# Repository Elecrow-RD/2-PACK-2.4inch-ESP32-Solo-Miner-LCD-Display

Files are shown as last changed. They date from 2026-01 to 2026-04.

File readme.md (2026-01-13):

### 1, Product picture

### 2, Product version number

| | Hardware | Software | Remark |
| ---- | --- | --- | --- |
| 1 | V1.0 | V1.0 | latest |

### 3, product information

| **Main Chip-ESP32-P4NRW32** | |
| --- | --- |
| CPU/SoC | **ESP32-P4**RISC-V 32-bit dual-core processor for HP systems, running at up to 400 MHz;RISC-V 32-bit single-core processor for LP systems, running at up to 40 MHz |
| System Memory | 768 KB L2MEM (HP) 32 KB SRAM (LP) 8 KB TCM 32 MB PSRAM |
| Memory | 128 KB ROM (HP) 16 KB ROM (LP) 16 MB Flash |
| Development Language | MicroPython, Rust, Lua |
| Development Environment | ESP-IDF、Arduino IDE、LVGL |
| **Screen** | |
| Size | 7.0 inch |
| Resolution | 1024*600 |
| Display Panel | IPS Panel |
| Touch Panel | Capacitive Touch, Single/5-point Touch |
| Viewing Angle | 178° |
| Brightness | 400 cd/m²(Typ.) |
| Color Depth | 16.7M (8-bit) |
| **Wireless Communication - Onboard Antenna** | |
| WiFi | Support 2.4GHz(Wi-Fi6), 802.11a/b/g/n |
| Bluetooth | Support Bluetooth 5.3 and BLE |
| Other | Zigbee, LoRa, nRF2401, Matter, Thread (**Optional**) |
| **Interface/Function** | |
| Interface | USB2.0, UART, I2C, GPIO female headers, SD card holder, battery socket, speaker jack, camera header, module female headers, etc. |
| Function | Audio amplifier, battery charge management, USB to UART, dual microphones, dual speakers etc. |
| **Button/LED Indicator** | |
| Reset Button | Yes, press to reset the device |
| Boot Button | Yes, press and hold the power button to burn the program |
| Power Button | Switch On/Off |
| PWR | Device power on/off indication |
| CHG | Lithium battery charging status, Low battery state |
| **Other** | |
| Installation method | All around mounting holes(M3 3.2mm), embedded, shell assembly |
| Operating temperature | -20~70 °C |
| Storage temperature | -30~80 °C |
| Power Input | 5V/2A, USB or UART terminal |
| Active Area | 155mm*87mm |
| Dimensions | 180*105mm |

### 4, Use the driver module

| Name | dependency library |
| ---- | --- |
| LVGL | lvgl/lvgl@8.3.11 |

### 5,Quick Start
##### Arduino IDE starts

1.Download the library files used by this product to the 'libraries' folder.

C:\Users\Documents\Arduino\libraries\



2.Open the Arduino IDE



3.Open the code configuration environment and burn it



##### ESP-IDF starts

1.Right-click on an empty space in the project folder and select "Open with VS Code" to open the project.


2.In the IDF plug-in, select the port, then compile and flash


### 6,Folder structure.
|--3D file： Contains 3D model files (.stp) for the hardware. These files can be used for visualization, enclosure design, or integration into CAD software.

|--Datasheet: Includes datasheets for components used in the project, providing detailed specifications, electrical characteristics, and pin configurations.

|--Eagle_SCH&PCB: Contains **Eagle CAD** schematic (`.sch`) and PCB layout (`.brd`) files. These are used for circuit design and PCB manufacturing.

|--example: Provides example code and projects to demonstrate how to use the hardware and libraries. These examples help users get started quickly.

|--factory_firmware: Stores pre-compiled factory firmware that can be directly flashed onto the device. This ensures the device runs the default functionality.

|--factory_sourcecode:  Contains the source code for the factory firmware, allowing users to modify and rebuild the firmware as needed.

|--libraries: Includes necessary libraries required for compiling and running the project. These libraries provide drivers and additional functionalities for the hardware.

### 7,Pin definition

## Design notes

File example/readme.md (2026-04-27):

Version **V1.0_A_green_circular_sticker_on_the_back** is a new release. In this version, the X-axis touch sensitivity is reversed compared to the previous version (1.0). All other features remain unchanged.

Version **V1.0_A_green_circular_sticker_on_the_back** has a green circular sticker on the back.


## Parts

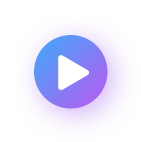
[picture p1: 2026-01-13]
example/V1.0_A_green_circular_sticker_on_the_back/IDF_Code/DHT_screen_2.4_base/components/lvgl-3/demos/music/assets/png/480_png/btn_play.png

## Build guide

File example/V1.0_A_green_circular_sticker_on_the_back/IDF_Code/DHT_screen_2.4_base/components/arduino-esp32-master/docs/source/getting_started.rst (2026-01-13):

###############
Getting Started
###############

About Arduino ESP32
-------------------

Welcome to the Arduino ESP32 support documentation! Here you will find important information on how to use the project.

First Things First
------------------

.. note::
    Before continuing, we must be clear that this project is supported by `Espressif Systems`_ and the community.
    Everyone is more than welcome to contribute back to this project.

ESP32 is a single 2.4 GHz Wi-Fi-and-Bluetooth SoC (System On a Chip) designed by `Espressif Systems`_.

ESP32 is designed for mobile, wearable electronics, and Internet-of-Things (IoT) applications. It features all the state-of-the-art characteristics 
of low-power chips, including fine-grained clock gating, multiple power modes,and dynamic power scaling. For instance, in a low-power IoT sensor 
hub application scenario, ESP32 is woken-up periodically and only when a specified condition is detected. Low-duty cycle is used to minimize the 
amount of energy that the chip expends. 

The output of the power amplifier is also adjustable, thus contributing to an optimal trade-off between communication range, data rate and 
power consumption.

The ESP32 series is available as a chip or module.

.. _supported_socs:

Supported SoC's
---------------

Here are the ESP32 series supported by the Arduino-ESP32 project:

======== ====== =========== ===================================
SoC      Stable Development Datasheet
======== ====== =========== ===================================
ESP32    Yes    Yes         `ESP32`_
ESP32-S2 Yes    Yes         `ESP32-S2`_
ESP32-C3 Yes    Yes         `ESP32-C3`_
ESP32-S3 No     Yes         `ESP32-S3`_
======== ====== =========== ===================================

See `Boards <boards/boards.html>`_ for more details about ESP32 development boards.

Arduino Core Reference
----------------------

This documentation is built on the ESP32 and we are not going to cover the common Arduino API. To see the Arduino reference documentation, 
please consider reading the official documentation.

Arduino Official Documentation: `Arduino Reference`_.

Supported Operating Systems
---------------------------

+-------------------+-------------------+-------------------+
|     |       |       |
+-------------------+-------------------+-------------------+
| Windows           | Linux             | macOS             |
+-------------------+-------------------+-------------------+





Supported IDEs
---------------------------

Here is the list of supported IDE for Arduino ESP32 support integration.

+-------------------+-------------------+
|     |         |
+-------------------+-------------------+
| Arduino IDE       | PlatformIO        |
+-------------------+-------------------+




See `Installing Guides <installing.html>`_ for more details on how to install the Arduino ESP32 support.

Support
-------

This is an open project and it's supported by the community. Fell free to ask for help in one of the community channels.

Community
---------

The Arduino community is huge! You can find a lot of useful content on the Internet.
Here are some community channels where you may find information and ask for some help, if needed.

- `ESP32 Forum`_: Official Espressif Forum.
- `ESP32 Forum - Arduino`_: Official Espressif Forum for Arduino related discussions.
- `ESP32 Forum - Hardware`_: Official Espressif Forum for Hardware related discussions.
- `Gitter`_
- `Espressif MCUs (Discord)`_
- `ESP32 on Reddit`_

Issues Reporting
----------------

Before opening a new issue, please read this: 

Be sure to search for a similar reported issue. This avoids duplicating or creating noise in the GitHub Issues reporting.
We also have the troubleshooting guide to save your time on the most common issues reported by users.

For more details about creating new Issue, see the `Issue Template <https://github.com/espressif/arduino-esp32/blob/master/.github/ISSUE_TEMPLATE/Issue-report.yml>`_.

If you have any new idea, see the `Feature request Template <https://github.com/espressif/arduino-esp32/blob/master/.github/ISSUE_TEMPLATE/Feature-request.yml>`_.

First Steps
-----------

Here are the first steps to get the Arduino ESP32 support running.

To install Arduino-ESP32, please see the dedicated section on the Installation guide. We recommend you install it using the boards manager.

.. toctree::
    :maxdepth: 2
    
    How to Install <installing>
    Development Boards <boards/boards>

Examples
--------

After installing the toolchain into your environment, you will be able to see all the dedicated examples for the ESP32. These examples are located
in the examples menu or inside each library folder.

    https://github.com/espressif/arduino-esp32/tree/master/libraries

.. include:: common/datasheet.inc

Resources
---------

.. _Espressif Systems: https://www.espressif.com 
.. _Espressif Product Selector: https://products.espressif.com/
.. _Arduino.cc: https://www.arduino.cc/en/Main/Software
.. _Arduino Reference: https://www.arduino.cc/reference/en/
.. _ESP32 Forum: https://esp32.com
.. _ESP32 Forum - Arduino: https://esp32.com/viewforum.php?f=19
.. _ESP32 Forum - Hardware: https://esp32.com/viewforum.php?f=12
.. _Gitter: https://gitter.im/espressif/arduino-esp32
.. _Adafruit (Discord): https://discord.gg/adafruit
.. _Espressif MCUs (Discord): https://discord.gg/nKxMTnkD
.. _ESP32 on Reddit: https://www.reddit.com/r/esp32

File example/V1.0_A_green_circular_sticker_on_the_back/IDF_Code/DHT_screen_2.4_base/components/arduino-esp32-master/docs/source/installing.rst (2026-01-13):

##########
Installing
##########

This guide will show how to install the Arduino-ESP32 support.

Before Installing
-----------------

We recommend you install the support using your favorite IDE, but other options are available depending on your operating system. 
To install Arduino-ESP32 support, you can use one of the following options.

Installing using Arduino IDE
----------------------------



This is the way to install Arduino-ESP32 directly from the Arduino IDE.

.. note::
   For overview of SoC's support, take a look on `Supported Soc's table <https://docs.espressif.com/projects/arduino-esp32/en/latest/getting_started.html#supported-soc-s>`_ where you can find if the particular chip is under stable or development release.

- Stable release link::

   https://raw.githubusercontent.com/espressif/arduino-esp32/gh-pages/package_esp32_index.json

- Development release link::

   https://raw.githubusercontent.com/espressif/arduino-esp32/gh-pages/package_esp32_dev_index.json

.. note::
   Starting with the Arduino IDE version 1.6.4, Arduino allows installation of third-party platform 
   packages using Boards Manager. We have packages available for Windows, macOS, and Linux.

To start the installation process using the Boards Managaer, follow these steps:

-  Install the current upstream Arduino IDE at the 1.8 level or later. The current version is at the `arduino.cc`_ website.

-  Start Arduino and open the Preferences window.



-  Enter one of the release links above into *Additional Board Manager URLs* field. You can add multiple URLs, separating them with commas.



-  Open Boards Manager from Tools > Board menu and install *esp32* platform (and do not forget to select your ESP32 board from Tools > Board menu after installation).



- Restart Arduino IDE.

Installing using PlatformIO
---------------------------



PlatformIO is a professional collaborative platform for embedded development. It has out-of-the-box support for ESP32 SoCs and allows working with Arduino ESP32 as well as ESP-IDF from Espressif without changing your development environment. PlatformIO includes lots of instruments for the most common development tasks such as debugging, unit testing, and static code analysis.

A detailed overview of the PlatformIO ecosystem and its philosophy can be found in `the official documentation <https://docs.platformio.org/en/latest/core/index.html>`_.

PlatformIO can be used in two flavors:

- `PlatformIO IDE <https://platformio.org/platformio-ide>`_ is a toolset for embedded C/C++ development available on Windows, macOS and Linux platforms

- `PlatformIO Core (CLI) <https://docs.platformio.org/en/latest/core/index.html>`_ is a command-line tool that consists of a multi-platform build system, platform and library managers and other integration components. It can be used with a variety of code development environments and allows integration with cloud platforms and web services

To install PlatformIO, you can follow this Getting Started, provided at `docs.platformio.org`_.

Using the stable code
*********************

.. note::
   A detailed overview of supported development boards, examples and frameworks can be found on `the official Espressif32 dev-platform page <https://registry.platformio.org/platforms/platformio/espressif32>`_ in the PlatformIO Registry.

The most reliable and easiest way to get started is to use the latest stable version of the ESP32 development platform that passed all tests/verifications and can be used in production.

Create a new project and select one of the available boards. You can change after by changing the `platformio.ini <https://docs.platformio.org/en/latest/projectconf/index.html>`_ file.

- For ESP32

.. code-block:: bash

   [env:esp32dev]
   platform = espressif32
   board = esp32dev
   framework = arduino

- For ESP32-S2 (ESP32-S2-Saola-1 board)

.. code-block:: bash

   [env:esp32-s2-saola-1]
   platform = espressif32
   board = esp32-s2-saola-1
   framework = arduino

- For ESP32-C3 (ESP32-C3-DevKitM-1 board)

.. code-block:: bash

   [env:esp32-c3-devkitm-1]
   platform = espressif32
   board = esp32-c3-devkitm-1
   framework = arduino

How to update to the latest code
********************************

To test the latest Arduino ESP32, you need to change your project *platformio.ini* accordingly.
The following configuration uses the upstream version of the Espressif development platform and the latest Arduino core directly from the Espressif GitHub repository:

.. code-block:: bash

   [env:esp32-c3-devkitm-1]
   platform = https://github.com/platformio/platform-espressif32.git
   board = esp32-c3-devkitm-1
   framework = arduino
   platform_packages =
       framework-arduinoespressif32 @ https://github.com/espressif/arduino-esp32#master

To get more information about PlatformIO, see the following links:

- `PlatformIO Core (CLI) <https://docs.platformio.org/en/latest/core/index.html>`_

- `PlatformIO Home <https://docs.platformio.org/en/latest/home/index.html>`_

- `Tutorials and Examples <https://docs.platformio.org/en/latest/tutorials/index.html>`_

- `Library Management <https://docs.platformio.org/en/latest/librarymanager/index.html>`_

Windows (manual installation)
-----------------------------

.. warning:: Arduino ESP32 core v2.x.x cannot be used on Windows 8.x x86 (32 bits), Windows 7 or earlier. The Windows 32 bits OS is no longer supported by this toolchain.

   The Arduino ESP32 v1.0.6 still works on WIN32. You might want to install python 3.8.x because it is the latest release supported by Windows 7.

Steps to install Arduino ESP32 support on Windows:

**Step 1**

1. Download and install the latest Arduino IDE ``Windows Installer`` from [arduino.cc](https://www.arduino.cc/en/Main/Software)
2. Download and install Git from [git-scm.com](https://git-scm.com/download/win)
3. Start ``Git GUI`` and do the following steps:

- Select ``Clone Existing Repository``



- Select source and destination
   - Sketchbook Directory: Usually ``C:/Users/[YOUR_USER_NAME]/Documents/Arduino`` and is listed underneath the "Sketchbook location" in Arduino preferences.
   - Source Location: ``https://github.com/espressif/arduino-esp32.git``
   - Target Directory: ``[ARDUINO_SKETCHBOOK_DIR]/hardware/espressif/esp32``
   - Click ``Clone`` to start cloning the repository

**Step 2**



**Step 3**



- open a `Git Bash` session pointing to ``[ARDUINO_SKETCHBOOK_DIR]/hardware/espressif/esp32`` and execute ```git submodule update --init --recursive``` 
- Open ``[ARDUINO_SKETCHBOOK_DIR]/hardware/espressif/esp32/tools`` and double-click ``get.exe``

**Step 4**



- When ```get.exe``` finishes, you should see the following files in the directory

**Step 5**



1. Plug your ESP32 board and wait for the drivers to install (or install manually any that might be required)
2. Start Arduino IDE
3. Select your board in ``Tools > Board`` menu
4. Select the COM port that the board is attached to
5. Compile and upload (You might need to hold the boot button while uploading)



How to update to the latest code
********************************

1. Start ``Git GUI`` and you should see the repository under ``Open Recent Repository``. Click on it!



1. From menu ``Remote`` select ``Fetch from`` > ``origin``



1. Wait for git to pull any changes and close ``Git GUI``
2. Open ``[ARDUINO_SKETCHBOOK_DIR]/hardware/espressif/esp32/tools`` and double-click ``get.exe``



Linux
-----



Debian/Ubuntu
*************

- Install latest Arduino IDE from `arduino.cc`_.

- Open Terminal and execute the following command (copy -> paste and hit enter):

.. code-block:: bash

   sudo usermod -a -G dialout $USER && \
   sudo apt-get install git && \
   wget https://bootstrap.pypa.io/get-pip.py && \
   sudo python3 get-pip.py && \
   sudo pip3 install pyserial && \
   mkdir -p ~/Arduino/hardware/espressif && \
   cd ~/Arduino/hardware/espressif && \
   git clone https://github.com/espressif/arduino-esp32.git esp32 && \
   cd esp32/tools && \
   python3 get.py

- Restart Arduino IDE.

- If you have Arduino installed to ~/, modify the installation as follows, beginning at `mkdir -p ~/Arduino/hardware`:

.. code-block:: bash

   cd ~/Arduino/hardware
   mkdir -p espressif && \
   cd espressif && \
   git clone https://github.com/espressif/arduino-esp32.git esp32 && \
   cd esp32/tools && \
   python3 get.py

Fedora
******

- Install the latest Arduino IDE from `arduino.cc`_.

.. note::
   Command ``$ sudo dnf -y install arduino`` will most likely install an older release.

- Open Terminal and execute the following command (copy -> paste and hit enter):

.. code-block:: bash

   sudo usermod -a -G dialout $USER && \
   sudo dnf install git python3-pip python3-pyserial && \
   mkdir -p ~/Arduino/hardware/espressif && \
   cd ~/Arduino/hardware/espressif && \
   git clone https://github.com/espressif/arduino-esp32.git esp32 && \
   cd esp32/tools && \
   python get.py

- Restart Arduino IDE.

openSUSE
********

- Install the latest Arduino IDE from `arduino.cc`_.

- Open Terminal and execute the following command (copy -> paste and hit enter):

.. code-block:: bash

   sudo usermod -a -G dialout $USER && \
   if [ `python --version 2>&1 | grep '2.7' | wc -l` = "1" ]; then \
   sudo zypper install git python-pip python-pyserial; \
   else \
   sudo zypper install git python3-pip python3-pyserial; \
   fi && \
   mkdir -p ~/Arduino/hardware/espressif && \
   cd ~/Arduino/hardware/espressif && \
   git clone https://github.com/espressif/arduino-esp32.git esp32 && \
   cd esp32/tools && \
   python get.py

- Restart Arduino IDE.

macOS
-----

- Install the latest Arduino IDE from `arduino.cc`_.

- Open Terminal and execute the following command (copy -> paste and hit enter):

.. code-block:: bash

   mkdir -p ~/Documents/Arduino/hardware/espressif && \
   cd ~/Documents/Arduino/hardware/espressif && \
   git clone https://github.com/espressif/arduino-esp32.git esp32 && \
   cd esp32/tools && \
   python get.py 

Where ``~/Documents/Arduino`` represents your sketch book location as per "Arduino" > "Preferences" > "Sketchbook location" (in the IDE once started). Adjust the command above accordingly.

- If you get the error below, install through the command line dev tools with `xcode-select --install` and try the command above again:

.. code-block:: bash

   xcrun: error: invalid active developer path (/Library/Developer/CommandLineTools), missing xcrun at: /Library/Developer/CommandLineTools/usr/bin/xcrun

- Run the command:

.. code-block:: bash

   xcode-select --install

- Try ``python3`` instead of ``python`` if you get the error: ``IOError: [Errno socket error] [SSL: TLSV1_ALERT_PROTOCOL_VERSION] tlsv1 alert protocol version (_ssl.c:590)`` when running ``python get.py``

- If you get the following error when running ``python get.py`` urllib.error.URLError: <urlopen error SSL: CERTIFICATE_VERIFY_FAILED, go to Macintosh HD > Applications > Python3.6 folder (or any other python version), and run the following scripts: Install Certificates.command and Update Shell Profile.command

- Restart Arduino IDE.

.. _Arduino.cc: https://www.arduino.cc/en/Main/Software
.. _docs.platformio.org: https://docs.platformio.org/en/latest/integration/ide/pioide.html

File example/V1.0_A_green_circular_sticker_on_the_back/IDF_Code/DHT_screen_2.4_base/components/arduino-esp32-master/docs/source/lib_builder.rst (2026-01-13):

###############
Library Builder
###############

About
-----

Espressif provides a `tool <https://github.com/espressif/esp32-arduino-lib-builder>`_ to simplify building your own compiled libraries for use in Arduino IDE (or your favorite IDE).

This tool can be used to change the project or a specific configuration according to your needs.

Installing
----------

To install the Library Builder into your environment, please, follow the instructions below.

- Clone the ESP32 Arduino lib builder:

.. code-block:: bash

    git clone https://github.com/espressif/esp32-arduino-lib-builder

- Go to the ``esp32-arduino-lib-builder`` folder:

.. code-block:: bash

    cd esp32-arduino-lib-builder

- Build:

.. code-block:: bash

    ./build.sh

If everything works, you may see the following message: ``Successfully created esp32 image.``

Dependencies
************

To build the library you will need to install some dependencies. Maybe you already have installed it, but it is a good idea to check before building.

- Install all dependencies (**Ubuntu**):

.. code-block:: bash

    sudo apt-get install git wget curl libssl-dev libncurses-dev flex bison gperf cmake ninja-build ccache jq

- Install Python and upgrade pip:

.. code-block:: bash

    sudo apt-get install python3
    sudo pip install --upgrade pip

- Install all required packages:

.. code-block:: bash

    pip install --user setuptools pyserial click cryptography future pyparsing pyelftools

Building
--------

If you have all the dependencies met, it is time to build the libraries.

To build using the default configuration:

.. code-block:: bash

    ./build.sh

Custom Build
************

There are some options to help you create custom libraries. You can use the following options:

Usage
^^^^^

.. code-block:: bash

    build.sh [-s] [-A arduino_branch] [-I idf_branch] [-i idf_commit] [-c path] [-t <target>] [-b <build|menuconfig|idf_libs|copy_bootloader|mem_variant>] [config ...]

Skip Install/Update
^^^^^^^^^^^^^^^^^^^

Skip installing/updating of ESP-IDF and all components

.. code-block:: bash

    ./build.sh -s

This option can be used if you already have the ESP-IDF and all components already in your environment.

Set Arduino-ESP32 Branch
^^^^^^^^^^^^^^^^^^^^^^^^

Set which branch of arduino-esp32 to be used for compilation

.. code-block:: bash

    ./build.sh -A <arduino_branch>

Set ESP-IDF Branch
^^^^^^^^^^^^^^^^^^

Set which branch of ESP-IDF is to be used for compilation

.. code-block:: bash

    ./build.sh -I <idf_branch>

Set the ESP-IDF Commit
^^^^^^^^^^^^^^^^^^^^^^

Set which commit of ESP-IDF to be used for compilation

.. code-block:: bash

    ./build.sh -i <idf_commit>

Deploy
^^^^^^

Deploy the build to github arduino-esp32

.. code-block:: bash

    ./build.sh -d

Set the Arduino-ESP32 Destination Folder
^^^^^^^^^^^^^^^^^^^^^^^^^^^^^^^^^^^^^^^^

Set the arduino-esp32 folder to copy the result to. ex. '$HOME/Arduino/hardware/espressif/esp32'

.. code-block:: bash

    ./build.sh -c <path>

This function is used to copy the compiled libraries to the Arduino folder.

Set the Target
^^^^^^^^^^^^^^

Set the build target(chip). ex. 'esp32s3'

.. code-block:: bash

    ./build.sh -t <target>

This build command will build for the ESP32-S3 target. You can specify other targets.

* esp32
* esp32s2
* esp32c3
* esp32s3

Set Build Type
^^^^^^^^^^^^^^

Set the build type. ex. 'build' to build the project and prepare for uploading to a board.

.. note:: This command depends on the ``-t`` argument.

.. code-block:: bash

    ./build.sh -t esp32 -b <build|menuconfig|idf_libs|copy_bootloader|mem_variant>

Additional Configuration
^^^^^^^^^^^^^^^^^^^^^^^^

Specify additional configs to be applied. ex. 'qio 80m' to compile for QIO Flash@80MHz. Requires -b

.. note:: This command requires the ``-b`` to work properly.

.. code-block:: bash

    ./build.sh -t esp32 -b idf_libs qio 80m

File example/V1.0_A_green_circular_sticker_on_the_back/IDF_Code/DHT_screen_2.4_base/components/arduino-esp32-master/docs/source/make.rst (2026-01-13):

==============
makeEspArduino
==============

The `makeEspArduino <https://github.com/plerup/makeEspArduino>`_ is a generic makefile for any ESP8266/ESP32 Arduino project. 
Using it instead of the Arduino IDE makes it easier to do automated and production builds.

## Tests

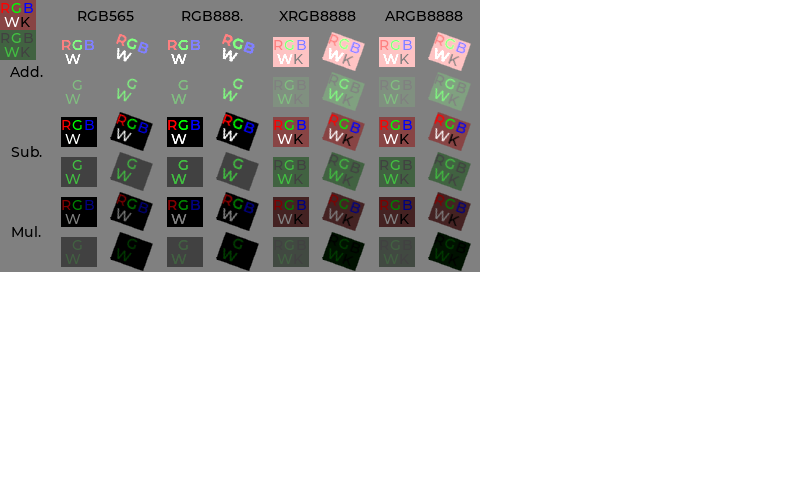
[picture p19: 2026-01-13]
example/V1.0_A_green_circular_sticker_on_the_back/IDF_Code/DHT_screen_2.4_base/components/lvgl-3/tests/ref_imgs_vg_lite/draw/render/argb8888/demo_render_blend_mode_opa_255.png

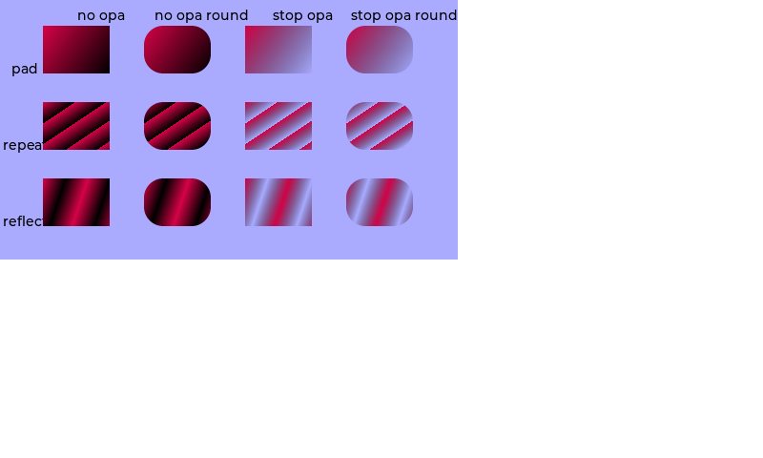
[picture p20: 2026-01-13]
example/V1.0_A_green_circular_sticker_on_the_back/IDF_Code/DHT_screen_2.4_base/components/lvgl-3/tests/ref_imgs/draw/render/xrgb8888/demo_render_linear_gradient_opa_255.png

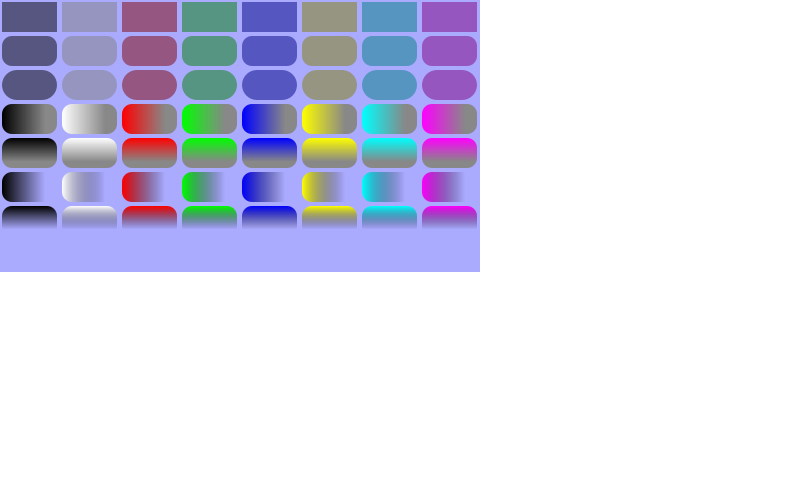
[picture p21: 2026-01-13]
example/V1.0_A_green_circular_sticker_on_the_back/IDF_Code/DHT_screen_2.4_base/components/lvgl-3/tests/ref_imgs_vg_lite/draw/render/argb8888/demo_render_fill_opa_128.png

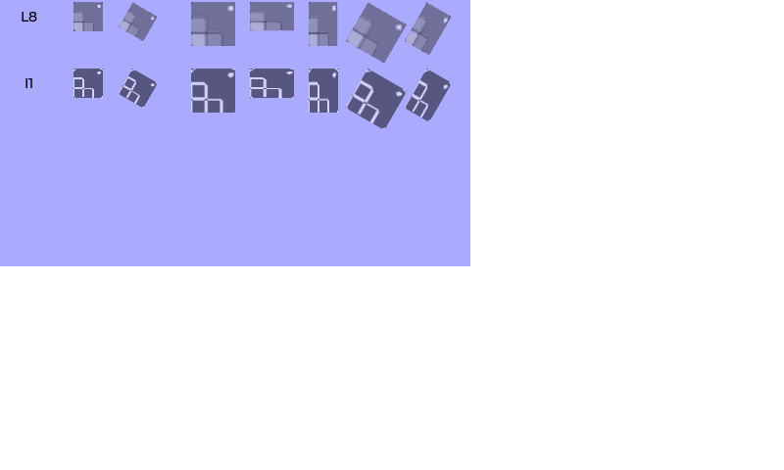
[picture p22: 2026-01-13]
example/V1.0_A_green_circular_sticker_on_the_back/IDF_Code/DHT_screen_2.4_base/components/lvgl-3/tests/ref_imgs/draw/render/xrgb8888/demo_render_image_normal_2_opa_128.png

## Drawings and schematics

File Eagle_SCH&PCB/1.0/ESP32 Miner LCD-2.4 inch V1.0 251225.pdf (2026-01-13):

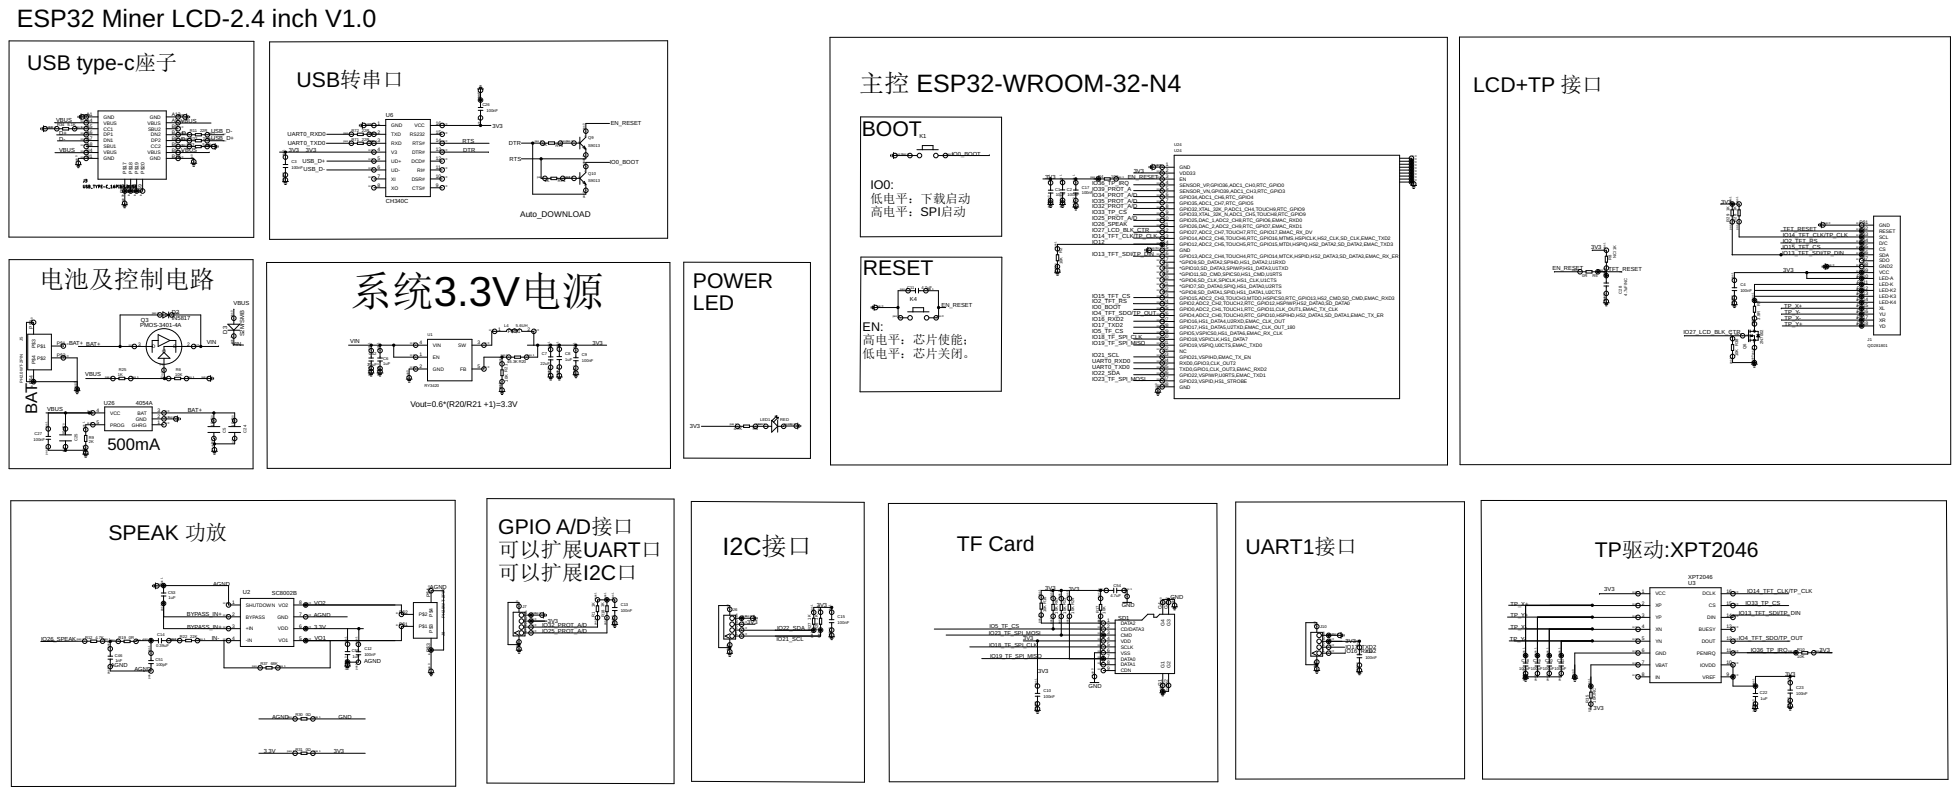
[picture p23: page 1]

BAT ESP32 Miner LCD-2.4 inch V1.0

pas 1 pas 1 pas 1 pas 1 sup 0

pas 0 pas 0 pas 1 pas 1

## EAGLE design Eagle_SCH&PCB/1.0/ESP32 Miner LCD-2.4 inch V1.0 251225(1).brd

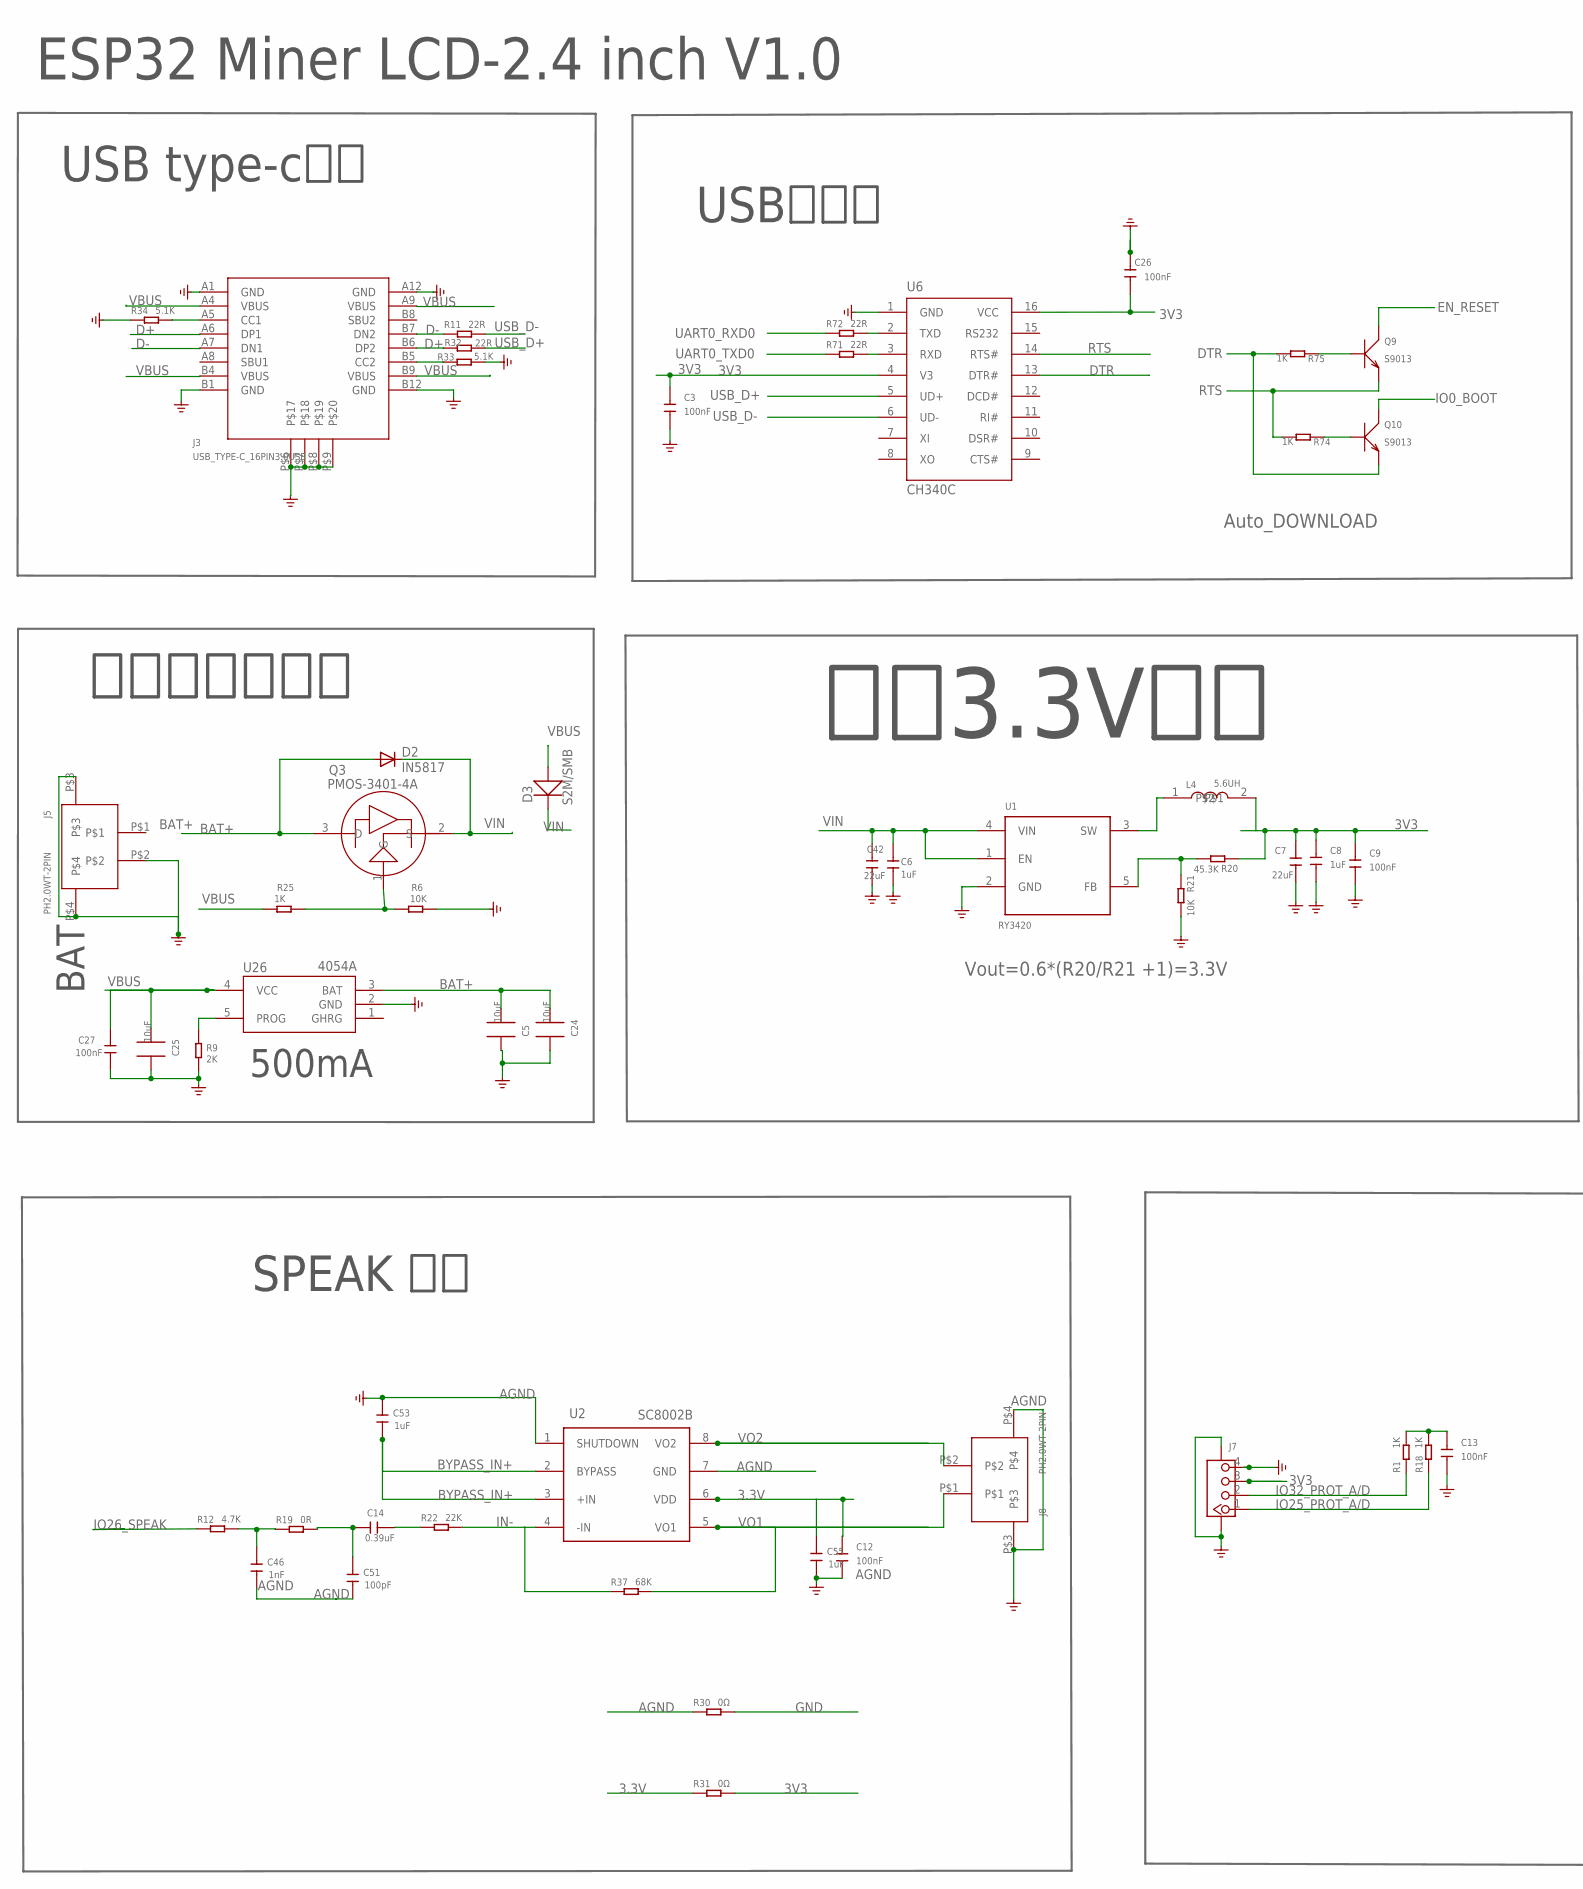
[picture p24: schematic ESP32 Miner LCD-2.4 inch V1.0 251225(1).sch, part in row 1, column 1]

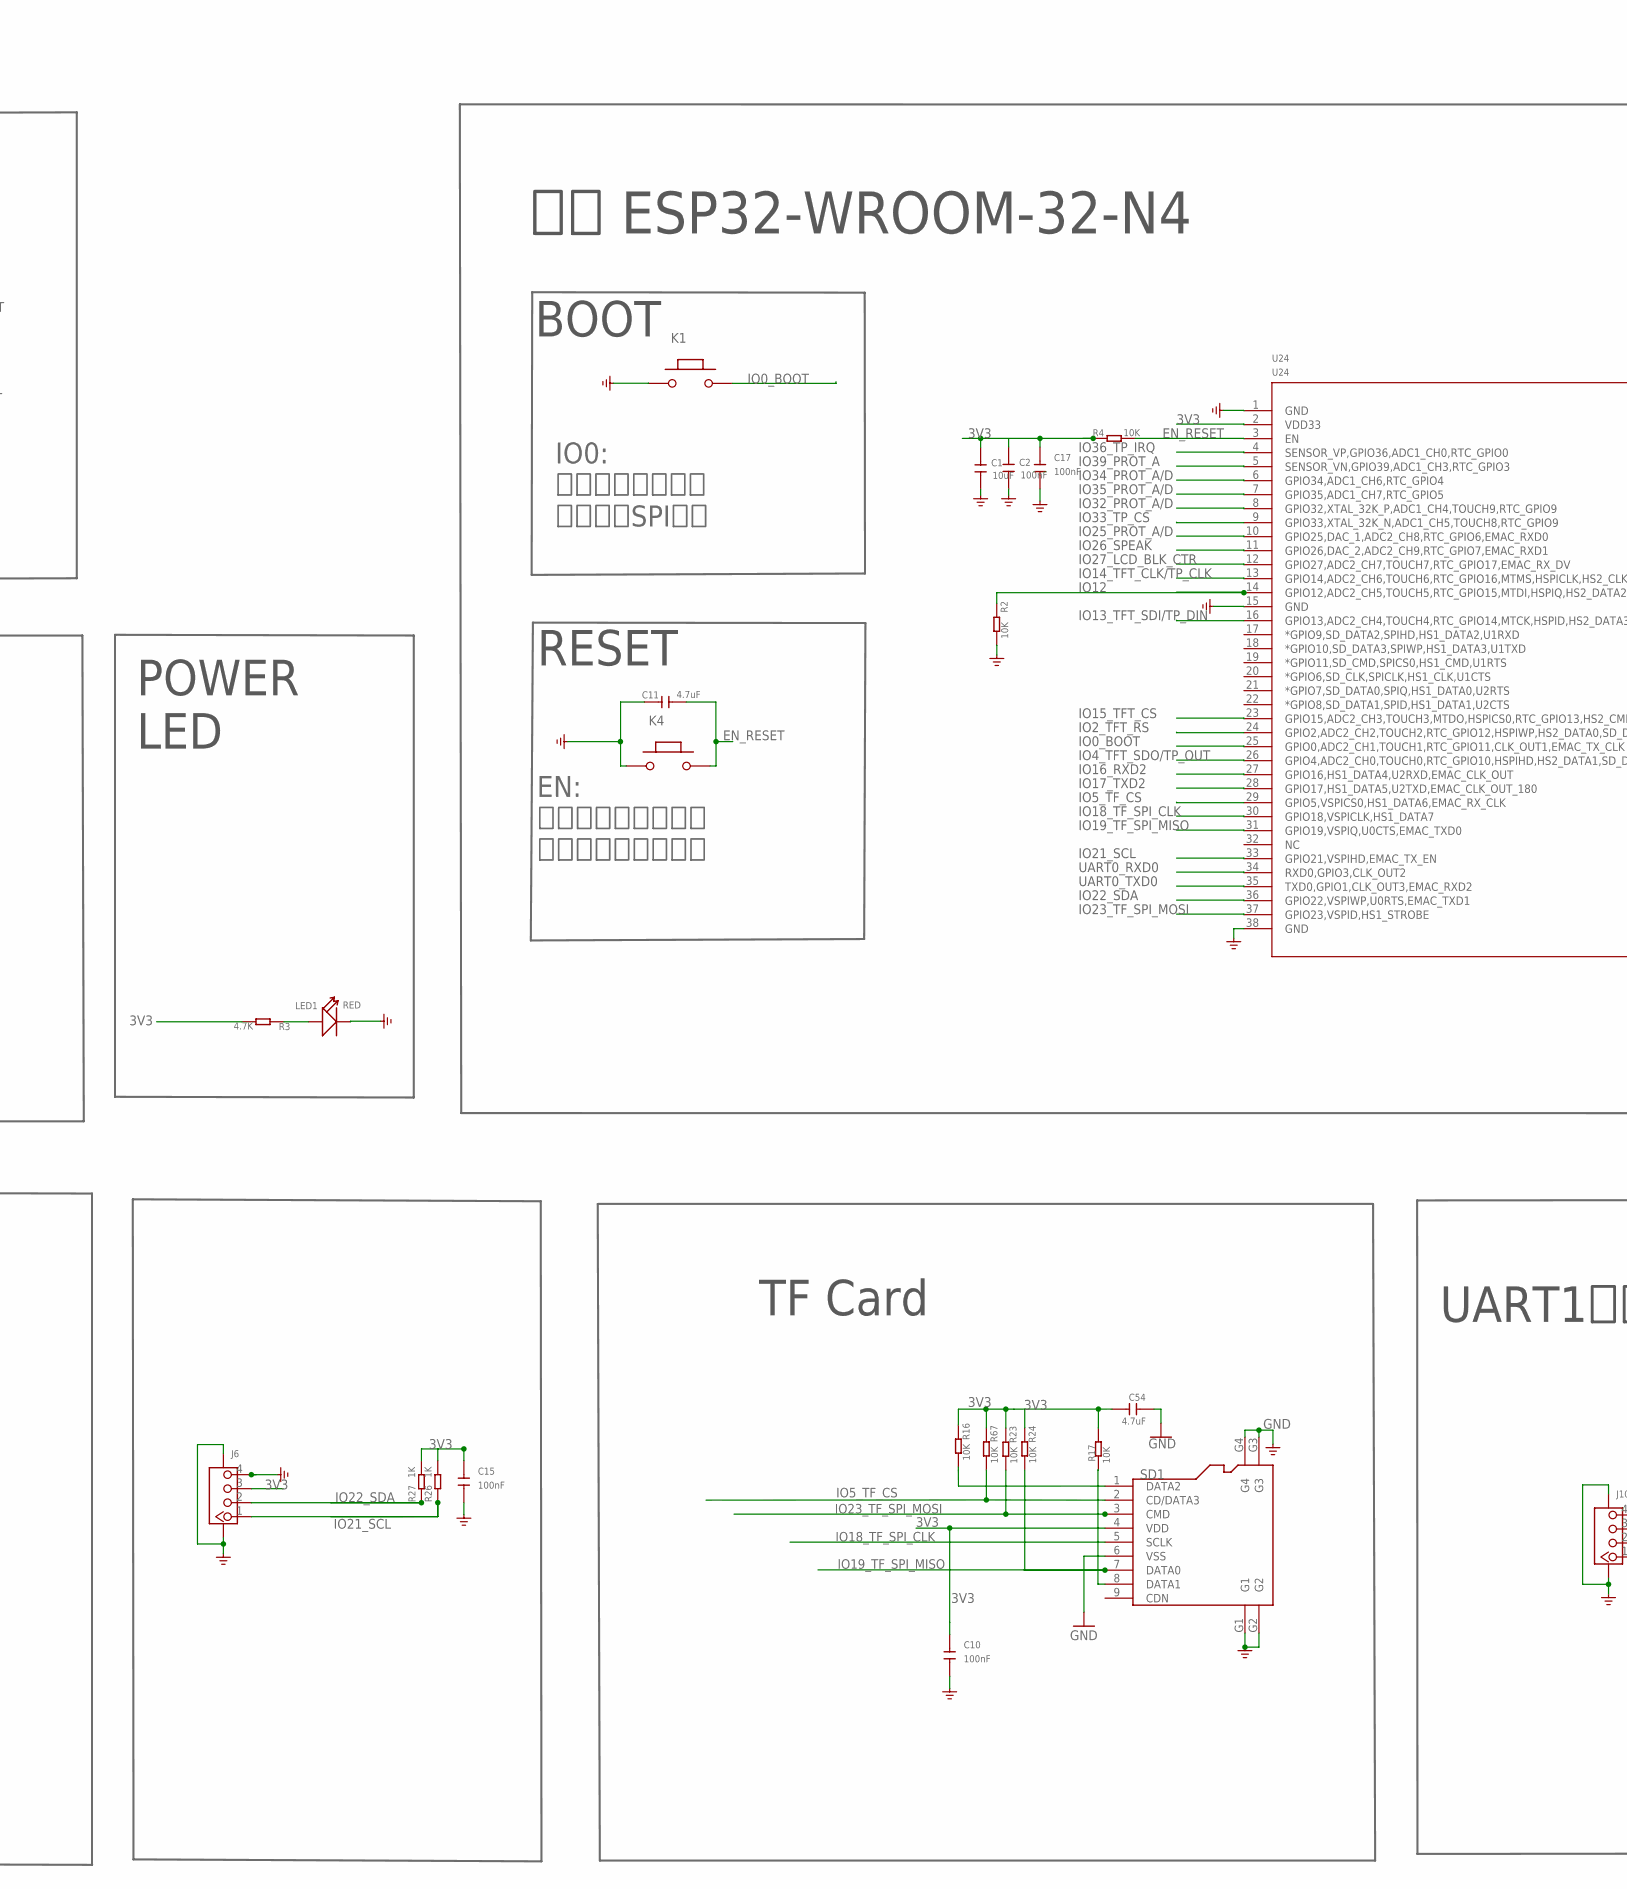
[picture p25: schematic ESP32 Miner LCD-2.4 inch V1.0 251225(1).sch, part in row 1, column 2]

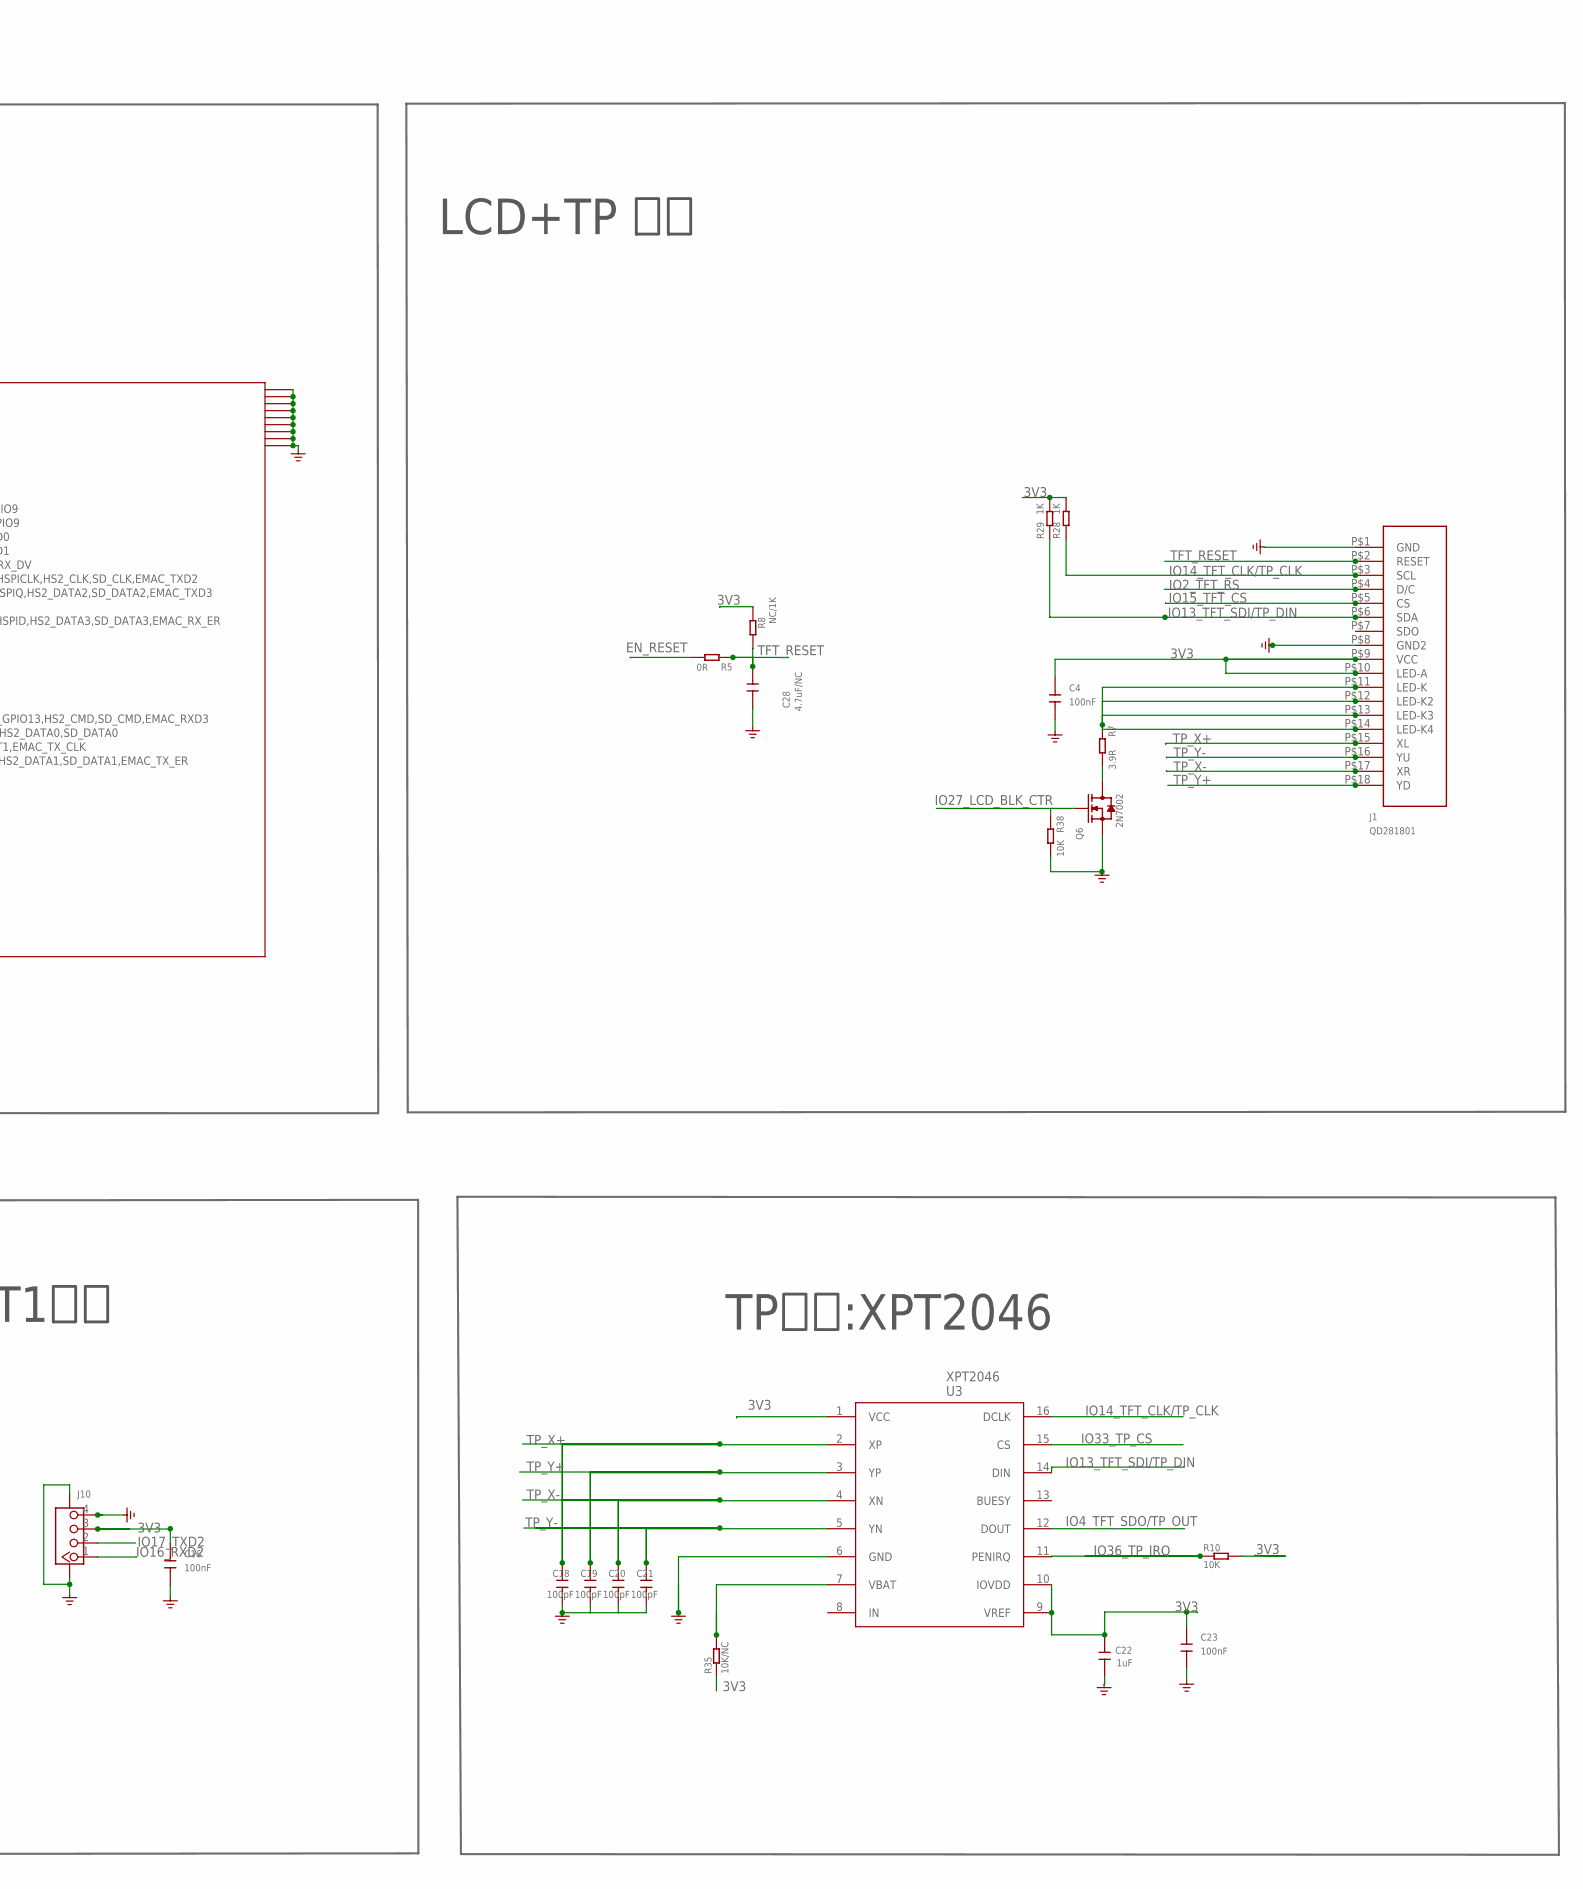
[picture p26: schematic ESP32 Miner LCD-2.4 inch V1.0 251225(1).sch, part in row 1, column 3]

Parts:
C1: 10uF; DISCRETE_C0603
C2: 100nF; DISCRETE_C0603
C3, C4, C9, C10, C12, C13, C15, C16, C17, C23, C26: 100nF; 0603
C5, C24, C25: 10uF; 0805_S
C6, C8: 1uF; 0603
C7, C42: 22uF; 0805
C11: 4.7uF; 0603
C14: 0.39uF; DISCRETE_C0603
C18, C19, C20, C21: 100pF; 0603
C22, C53, C55: 1uF; DISCRETE_C0603
C27: 100nF; C0603
C28: 4.7uF/NC; 0603
C46: 1nF; DISCRETE_C0603
C51: 100pF; DISCRETE_C0603
C54: 4.7uF; DISCRETE_C0603
D2: IN5817; DO-214AC
D3: S2M/SMB; 214AB
J1: QD281801; QD241801-18PIN*0.8
J3: USB_TYPE-C_16PIN3.0USB; KEVIN_3.0TYPEC-SMD
J5, J8: PH2.0WT-2PIN
J6, J7, J10: CONNECTOR_TWIG-4P-2.0-SMD-FEMALE-REINFORCE90D; CONNECTOR_4P-SMD-2.0-90D
K1, K4: BUTTON; 157SW
L4: 5.6UH; CD54_CD54
LED1: RED; DISCRETE_LED-0603
Q3: PMOS-3401-4A; SOT-23
Q6: 2N7002; SOT23
Q9, Q10: S9013; SOT23@1
R1, R18, R25, R26, R27, R28, R29, R74, R75: 1K; DISCRETE_R0603
R2, R6, R10, R16, R17, R21, R23, R24, R38, R67: 10K; DISCRETE_R0603
R3, R12: 4.7K; DISCRETE_R0603
R4: 10K; R0603
R5, R19: 0R; DISCRETE_R0603
R7: 3.9R; DISCRETE_R0603
R8: NC/1K; DISCRETE_R0603
R9: 2K; DISCRETE_R0603
R11, R32, R71, R72: 22R; DISCRETE_R0603
R20: 45.3K; DISCRETE_R0603
R22: 22K; DISCRETE_R0603
R30, R31: 0Ω; DISCRETE_R0603
R33, R34: 5.1K; DISCRETE_R0603
R35: 10K/NC; DISCRETE_R0603
R37: 68K; DISCRETE_R0603
SD1: HOLDER-MICROSD-9P; 9P-SMD-W/-RING
U1: RY3420; A_XBJ_SOT23-5
U2: SC8002B; AT24C02_SOP8
U3: XPT2046; XP2046-SSOP16
U6: CH340C; SOP-16
U24: U24; ESP32-WROOM-32-N4
U26: 4054A; SOP23-5

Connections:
3.3V: C12.2, C55.2, R31.1, U2.6 (VDD)
3V3: C1.2, C2.2, C3.2, C4.2, C7.2, C8.2, C9.2, C10.2, C13.2, C15.2, C16.2, C17.2, C22.2, C23.2, C26.1, C54.2, J1.P$9 (VCC), J1.P$10 (LED-A), J6.3, J7.3, J10.3, L4.2, R1.2, R3.2, R4.1, R8.2, R10.2, R16.1, R17.1, R18.2, R20.1, R23.1, R24.1, R26.2, R27.2, R28.2, R29.2, R31.2, R35.1, R67.1, SD1.4 (VDD), U3.1 (VCC), U3.9 (VREF), U3.10 (IOVDD), U6.4 (V3), U6.16 (VCC), U24.2 (VDD33)
AGND: C12.1, C46.1, C51.1, C53.2, C55.1, J8.P$3, J8.P$4, R30.1, U2.1 (SHUTDOWN), U2.7 (GND)
BAT+: C5.2, C24.2, D2.A, J5.P$1, Q3.3 (D), U26.3 (BAT)
BYPASS_IN+: C53.1, U2.2 (BYPASS), U2.3 (+IN)
D+: J3.A6 (DP1), J3.B6 (DP2), R32.1
D-: J3.A7 (DN1), J3.B7 (DN2), R11.1
DTR: Q10.2 (E), R75.2, U6.13 (DTR#)
EN_RESET: C11.1, K4.2, Q9.3 (C), R4.2, R5.2, U24.3 (EN)
GND: C1.1, C2.1, C3.1, C4.1, C5.1, C6.1, C7.1, C8.1, C9.1, C10.1, C11.2, C13.1, C15.1, C16.1, C17.1, C18.1, C19.1, C20.1, C21.1, C22.1, C23.1, C24.1, C25.1, C26.2, C27.2, C28.2, C42.1, C54.1, J1.P$1 (GND), J1.P$8 (GND2), J3.A1 (GND), J3.A12 (GND), J3.B1 (GND), J3.B12 (GND), J3.P$6, J3.P$7, J3.P$8, J3.P$9, J5.P$2, J5.P$3, J5.P$4, J6.4, J6.SS1, J6.SS2, J7.4, J7.SS1, J7.SS2, J10.4, J10.SS1, J10.SS2, K1.1, K4.1, LED1.-, Q6.2 (S), R2.2, R6.1, R9.2, R21.2, R30.2, R33.2, R34.1, R38.2, SD1.6 (VSS), SD1.G1, SD1.G2, SD1.G3, SD1.G4, U1.2 (GND), U3.6 (GND), U6.1 (GND), U24.1 (GND), U24.15 (GND), U24.38 (GND), U24.41 (GND), U24.42 (GND), U24.43 (GND), U24.44 (GND), U24.45 (GND), U24.46 (GND), U24.47 (GND), U24.48 (GND), U24.49 (GND), U26.2 (GND)
IN-: R22.2, R37.1, U2.4 (-IN)
IO0_BOOT: K1.2, Q10.3 (C), U24.25 (GPIO0,ADC2_CH1,TOUCH1,RTC_GPIO11,CLK_OU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)
IO2_TFT_RS: J1.P$4 (D/C), U24.24 (GPIO2,ADC2_CH2,TOUCH2,RTC_GPIO12,HSPIWP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)
IO4_TFT_SDO/TP_OUT: U3.12 (DOUT), U24.26 (GPIO4,ADC2_CH0,TOUCH0,RTC_GPIO10,HSPIHD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)
IO5_TF_CS: R67.2, SD1.2 (CD/DATA3), U24.29 (GPIO5,VSPICS0,HS1_DATA6,EMAC_RX_CLK)
IO12: R2.1, U24.14 (GPIO12,ADC2_CH5,TOUCH5,RTC_GPIO15,MTDI,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)
IO13_TFT_SDI/TP_DIN: J1.P$6 (SDA), R29.1, U3.14 (DIN), U24.16 (GPIO13,ADC2_CH4,TOUCH4,RTC_GPIO14,MTCK,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)
IO14_TFT_CLK/TP_CLK: J1.P$3 (SCL), R28.1, U3.16 (DCLK), U24.13 (GPIO14,ADC2_CH6,TOUCH6,RTC_GPIO16,MTMS,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)
IO15_TFT_CS: J1.P$5 (CS), U24.23 (GPIO15,ADC2_CH3,TOUCH3,MTDO,HSPICS0,RTC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)
IO16_RXD2: J10.1, U24.27 (GPIO16,HS1_DATA4,U2RXD,EMAC_CLK_OUT)
IO17_TXD2: J10.2, U24.28 (GPIO17,HS1_DATA5,U2TXD,EMAC_CLK_OUT_180)
IO18_TF_SPI_CLK: SD1.5 (SCLK), U24.30 (GPIO18,VSPICLK,HS1_DATA7)
IO19_TF_SPI_MISO: R24.2, SD1.7 (DATA0), U24.31 (GPIO19,VSPIQ,U0CTS,EMAC_TXD0)
IO21_SCL: J6.1, R26.1, U24.33 (GPIO21,VSPIHD,EMAC_TX_EN)
IO22_SDA: J6.2, R27.1, U24.36 (GPIO22,VSPIWP,U0RTS,EMAC_TXD1)
IO23_TF_SPI_MOSI: R23.2, SD1.3 (CMD), U24.37 (GPIO23,VSPID,HS1_STROBE)
IO25_PROT_A/D: J7.1, R18.1, U24.10 (GPIO25,DAC_1,ADC2_CH8,RTC_GPIO6,EMAC_RX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)
IO26_SPEAK: R12.1, U24.11 (GPIO26,DAC_2,ADC2_CH9,RTC_GPIO7,EMAC_RX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)
IO27_LCD_BLK_CTR: Q6.1 (G), R38.1, U24.12 (GPIO27,ADC2_CH7,TOUCH7,RTC_GPIO17,EMAC_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)
IO32_PROT_A/D: J7.2, R1.1, U24.8 (GPIO32,XTAL_32K_P,ADC1_CH4,TOUCH9,RTC_G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)
IO33_TP_CS: U3.15 (CS), U24.9 (GPIO33,XTAL_32K_N,ADC1_CH5,TOUCH8,RTC_G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)
IO34_PROT_A/D: U24.6 (GPIO34,ADC1_CH6,RTC_GPIO4)
IO35_PROT_A/D: U24.7 (GPIO35,ADC1_CH7,RTC_GPIO5)
IO36_TP_IRQ: R10.1, U3.11 (PENIRQ), U24.4 (SENSOR_VP,GPIO36,ADC1_CH0,RTC_GPIO0)
IO39_PROT_A: U24.5 (SENSOR_VN,GPIO39,ADC1_CH3,RTC_GPIO3)
unnamed: LED1.+, R3.1
unnamed: Q6.3 (D), R7.2
unnamed: C46.2, R12.2, R19.1
unnamed: R35.2, U3.7 (VBAT)
unnamed: R9.1, U26.5 (PROG)
unnamed: J1.P$11 (LED-K), J1.P$12 (LED-K2), J1.P$13 (LED-K3), J1.P$14 (LED-K4), R7.1
unnamed: L4.1, U1.3 (SW)
unnamed: J3.B5 (CC2), R33.1
unnamed: J3.A5 (CC1), R34.2
unnamed: Q3.1 (G), R6.2, R25.1
unnamed: R20.2, R21.1, U1.5 (FB)
unnamed: C14.1, C51.2, R19.2
unnamed: C14.2, R22.1
unnamed: Q9.1 (B), R75.1
unnamed: Q10.1 (B), R74.1
unnamed: R72.2, U6.2 (TXD)
unnamed: R71.2, U6.3 (RXD)
unnamed: R16.2, SD1.1 (DATA2)
unnamed: R17.2, SD1.8 (DATA1)
RTS: Q9.2 (E), R74.2, U6.14 (RTS#)
TFT_RESET: C28.1, J1.P$2 (RESET), R5.1, R8.1
TP_X+: C18.2, J1.P$15 (XL), U3.2 (XP)
TP_X-: C20.2, J1.P$17 (XR), U3.4 (XN)
TP_Y+: C19.2, J1.P$18 (YD), U3.3 (YP)
TP_Y-: C21.2, J1.P$16 (YU), U3.5 (YN)
UART0_RXD0: R72.1, U24.34 (RXD0,GPIO3,CLK_OUT2)
UART0_TXD0: R71.1, U24.35 (TXD0,GPIO1,CLK_OUT3,EMAC_RXD2)
USB_D+: R32.2, U6.5 (UD+)
USB_D-: R11.2, U6.6 (UD-)
VBUS: C25.2, C27.1, D3.1 (+), J3.A4 (VBUS), J3.A9 (VBUS), J3.B4 (VBUS), J3.B9 (VBUS), R25.2, U26.4 (VCC)
VIN: C6.2, C42.2, D2.C, D3.2 (-), Q3.2 (S), U1.1 (EN), U1.4 (VIN)
VO1: J8.P$1, R37.2, U2.5 (VO1)
VO2: J8.P$2, U2.8 (VO2)

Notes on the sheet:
Vout=0.6*(R20/R21 +1)=3.3V
系统3.3V电源
UART1接口
主控 ESP32-WROOM-32-N4
USB type-c座子
电池及控制电路
IO0: 低电平：下载启动 高电平：SPI启动
EN: 高电平：芯片使能； 低电平：芯片关闭。
USB转串口
SPEAK 功放
TF Card
BOOT
RESET
POWER LED
LCD+TP 接口
TP驱动:XPT2046
Auto_DOWNLOAD
500mA
BAT
ESP32 Miner LCD-2.4 inch V1.0

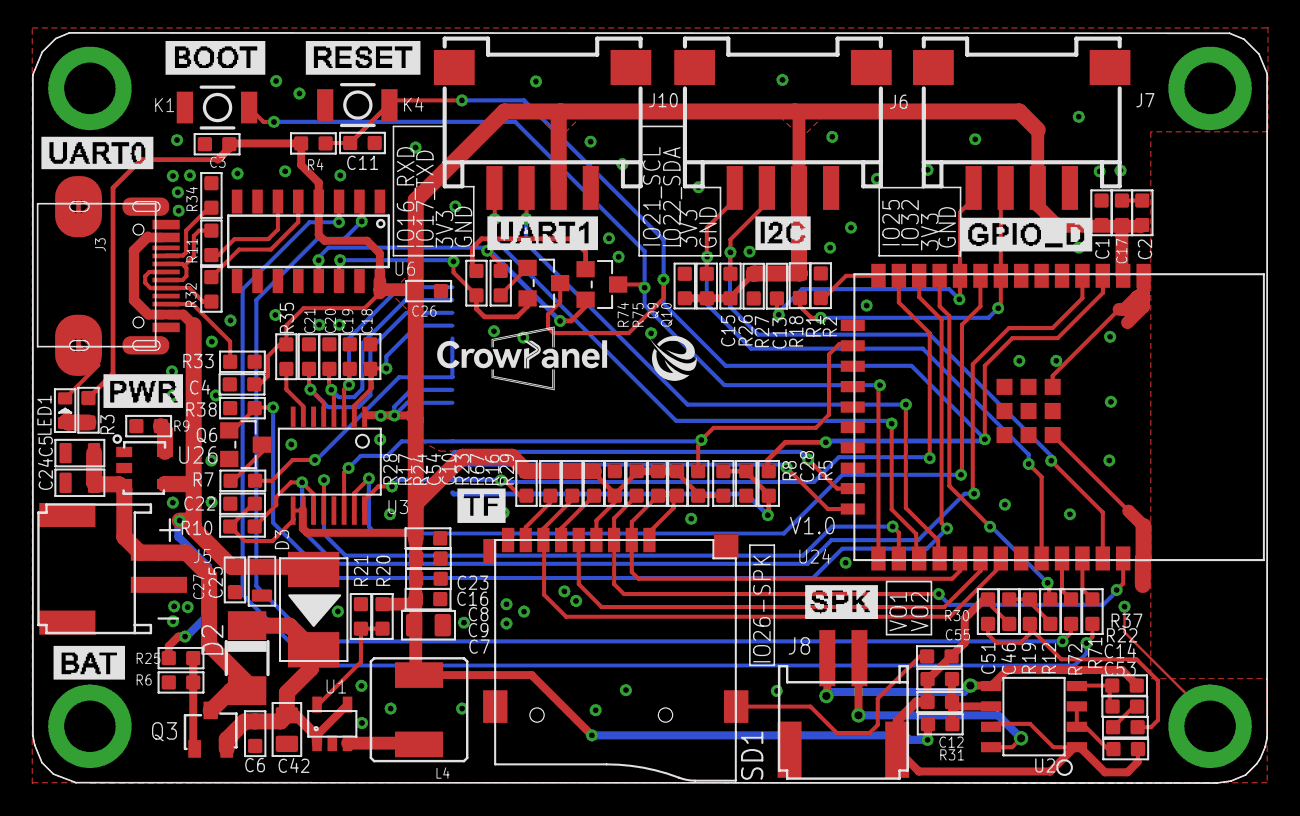
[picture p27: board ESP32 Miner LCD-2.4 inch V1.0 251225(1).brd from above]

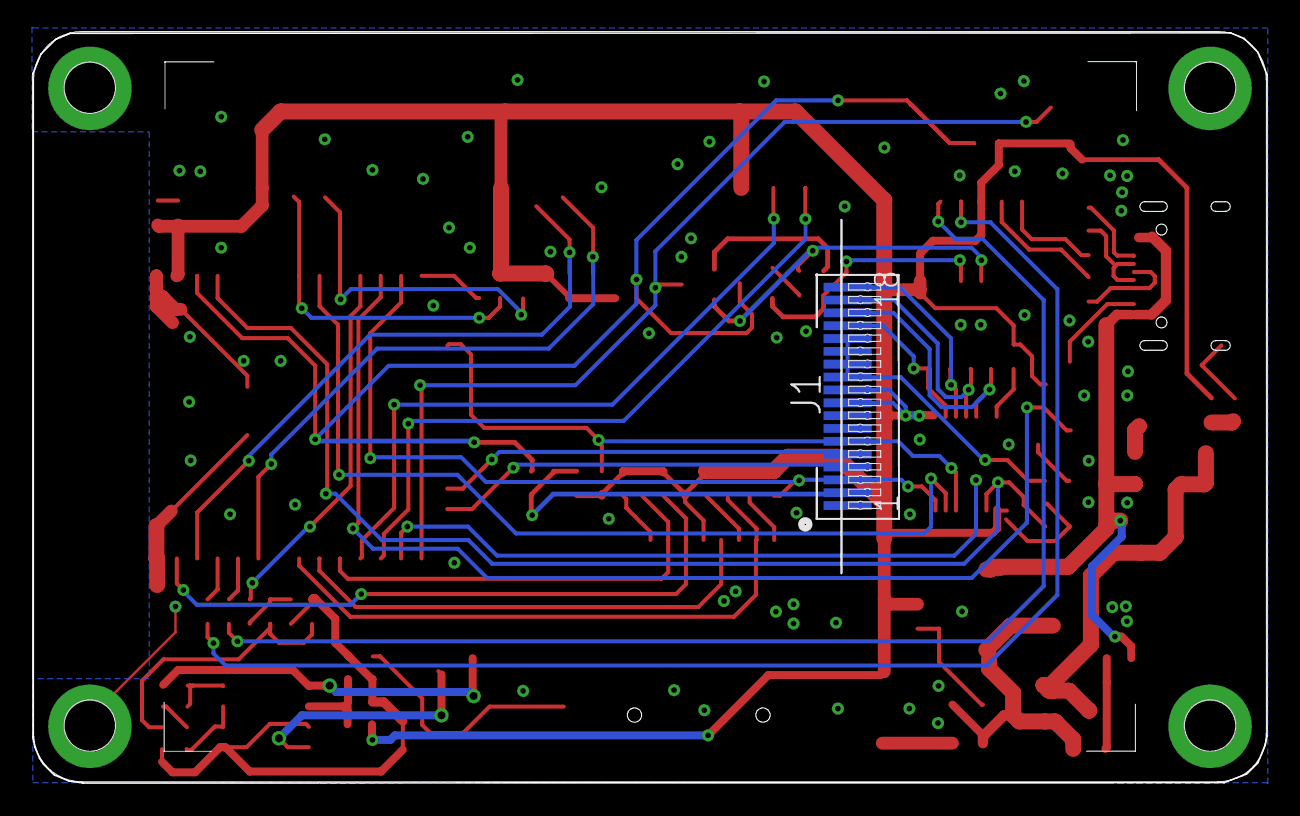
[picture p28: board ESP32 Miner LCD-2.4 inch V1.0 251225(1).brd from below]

Board: 2 copper layers, 76.8 x 46.7 mm, 100 parts (2 on the bottom side), 65 nets.

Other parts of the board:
U$2: 2.4板框
U$3: LOGE-2.0
U$37: LOGLE

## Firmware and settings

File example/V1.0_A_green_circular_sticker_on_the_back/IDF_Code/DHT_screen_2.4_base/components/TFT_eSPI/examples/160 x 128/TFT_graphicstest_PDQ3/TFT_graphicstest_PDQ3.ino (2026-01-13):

/*
 Adapted from the Adafruit and Xark's PDQ graphicstest sketch.

 This sketch uses the GLCD font only.

 Make sure all the display driver and pin connections are correct by
 editing the User_Setup.h file in the TFT_eSPI library folder.

 Note that yield() or delay(0) must be called in long duration for/while
 loops to stop the ESP8266 watchdog triggering.

 #########################################################################
 ###### DON'T FORGET TO UPDATE THE User_Setup.h FILE IN THE LIBRARY ######
 #########################################################################
 */


#include <TFT_eSPI.h> // Hardware-specific library
#include <SPI.h>

TFT_eSPI tft = TFT_eSPI();       // Invoke custom library

// These are used to get information about static SRAM and flash memory sizes
extern "C" char __data_start[];		// start of SRAM data
extern "C" char _end[];			// end of SRAM data (used to check amount of SRAM this program's variables use)
extern "C" char __data_load_end[];	// end of FLASH (used to check amount of Flash this program's code and data uses)


void setup()
{
  Serial.begin(115200);

  Serial.println(F("TFT 1.8\" SPI TFT Test!     ")); 
 
  tft.init();            // initialize LCD
}

// NOTE: This demo should run, but may look odd on 128x128 LCD (vs 128x160)

void loop(void)
{
  
  Serial.print(F(__DATE__ " " __TIME__ " - Flash=0x"));
  // These are not compatible with the ESP8266 core library
  //Serial.print((uint16_t)__data_load_end, HEX);
  //Serial.print(F(" RAM=0x"));
  //Serial.println((uint16_t)_end - (uint16_t)__data_start, HEX);
  Serial.println(F("Benchmark                Time (microseconds)"));

  uint32_t usecHaD = testHaD();
  Serial.print(F("HaD pushColor             "));
  Serial.println(usecHaD);
  delay(100);


  uint32_t usecFillScreen = testFillScreen();
  Serial.print(F("Screen fill              "));
  Serial.println(usecFillScreen);
  delay(100);

  tft.setRotation(1);
  uint32_t usecText = testText();
  Serial.print(F("Text                     "));
  Serial.println(usecText);
  delay(100);
  tft.setRotation(0);
  
  uint32_t usecPixels = testPixels();
  Serial.print(F("Pixels                   "));
  Serial.println(usecPixels);
  delay(100);

  uint32_t usecLines = testLines(TFT_BLUE);
  Serial.print(F("Lines                    "));
  Serial.println(usecLines);
  delay(100);

  uint32_t usecFastLines = testFastLines(TFT_RED, TFT_BLUE);
  Serial.print(F("Horiz/Vert Lines         "));
  Serial.println(usecFastLines);
  delay(100);

  uint32_t usecRects = testRects(TFT_GREEN);
  Serial.print(F("Rectangles (outline)     "));
  Serial.println(usecRects);
  delay(100);

  uint32_t usecFilledRects = testFilledRects(TFT_YELLOW, TFT_MAGENTA);
  Serial.print(F("Rectangles (filled)      "));
  Serial.println(usecFilledRects);
  delay(100);

  uint32_t usecFilledCircles = testFilledCircles(10, TFT_MAGENTA);
  Serial.print(F("Circles (filled)         "));
  Serial.println(usecFilledCircles);
  delay(100);

  uint32_t usecCircles = testCircles(10, TFT_WHITE);
  Serial.print(F("Circles (outline)        "));
  Serial.println(usecCircles);
  delay(100);

  uint32_t usecTriangles = testTriangles();
  Serial.print(F("Triangles (outline)      "));
  Serial.println(usecTriangles);
  delay(100);

  uint32_t usecFilledTrangles = testFilledTriangles();
  Serial.print(F("Triangles (filled)       "));
  Serial.println(usecFilledTrangles);
  delay(100);

  uint32_t usecRoundRects = testRoundRects();
  Serial.print(F("Rounded rects (outline)  "));
  Serial.println(usecRoundRects);
  delay(100);

  uint32_t usedFilledRoundRects = testFilledRoundRects();
  Serial.print(F("Rounded rects (filled)   "));
  Serial.println(usedFilledRoundRects);
  delay(100);

  Serial.println(F("Done!"));
  
  uint16_t c = 4;
  int8_t d = 1;
  for (int32_t i = 0; i < tft.height(); i++)
  {
    tft.drawFastHLine(0, i, tft.width(), c);
    c += d;
    if (c <= 4 || c >= 11)
      d = -d;
  }
  
  tft.setCursor(0, 0);
  tft.setTextColor(TFT_MAGENTA);

  tft.println(F("Bodmer's TFT_eSPI"));

  tft.setTextSize(1);
  tft.setTextColor(TFT_WHITE);
  tft.println(F("SPI TFT on ESP8266"));
  tft.println(F(""));
  tft.setTextSize(1);
  tft.setTextColor(tft.color565(0x80, 0x80, 0x80));

  // These are not compatible with the ESP8266 core library
  //tft.print(F("Flash=0x"));
  //tft.print((uint16_t)__data_load_end, HEX);
  //tft.print(F(" RAM=0x"));
  //tft.print((uint16_t)_end - (uint16_t)__data_start, HEX);

  tft.setTextColor(TFT_GREEN);
  tft.print(F("Benchmark        usec"));

  tft.setTextColor(TFT_CYAN);
  tft.print(F("HaD logo   "));
  tft.setTextColor(TFT_YELLOW);
  printnice(usecHaD);

  tft.setTextColor(TFT_CYAN);
  tft.print(F("Clear      "));
  tft.setTextColor(TFT_YELLOW);
  printnice(usecFillScreen);

  tft.setTextColor(TFT_CYAN);
  tft.print(F("Text       "));
  tft.setTextColor(TFT_YELLOW);
  printnice(usecText);

  tft.setTextColor(TFT_CYAN);
  tft.print(F("Pixels     "));
  tft.setTextColor(TFT_YELLOW);
  printnice(usecPixels);

  tft.setTextColor(TFT_CYAN);
  tft.print(F("Lines      "));
  tft.setTextColor(TFT_YELLOW);
  printnice(usecLines);

  tft.setTextColor(TFT_CYAN);
  tft.print(F("H/V Lines  "));
  tft.setTextColor(TFT_YELLOW);
  printnice(usecFastLines);

  tft.setTextColor(TFT_CYAN);
  tft.print(F("Rectangles "));
  tft.setTextColor(TFT_YELLOW);
  printnice(usecRects);

  tft.setTextColor(TFT_CYAN);
  tft.print(F("Rects-Fill "));
  tft.setTextColor(TFT_YELLOW);
  printnice(usecFilledRects);

  tft.setTextColor(TFT_CYAN);
  tft.print(F("Circles    "));
  tft.setTextColor(TFT_YELLOW);
  printnice(usecCircles);

  tft.setTextColor(TFT_CYAN);
  tft.print(F("CircleFill "));
  tft.setTextColor(TFT_YELLOW);
  printnice(usecFilledCircles);

  tft.setTextColor(TFT_CYAN);
  tft.print(F("Triangles  "));
  tft.setTextColor(TFT_YELLOW);
  printnice(usecTriangles);

  tft.setTextColor(TFT_CYAN);
  tft.print(F("Tris-Fill  "));
  tft.setTextColor(TFT_YELLOW);
  printnice(usecFilledTrangles);

  tft.setTextColor(TFT_CYAN);
  tft.print(F("Rnd-Rects  "));
  tft.setTextColor(TFT_YELLOW);
  printnice(usecRoundRects);

  tft.setTextColor(TFT_CYAN);
  tft.print(F("RRects-Fill"));
  tft.setTextColor(TFT_YELLOW);
  printnice(usedFilledRoundRects);

  tft.setTextSize(1);
  tft.println(F(""));
  tft.setTextColor(TFT_GREEN);
  tft.print(F("Benchmark Completed!"));

  delay(15 * 1000L);
}

void printnice(int32_t v)
{
  char  str[32] = { 0 };
  sprintf(str, "%d", v);
  for (char *p = (str+strlen(str))-3; p > str; p -= 3)
  {
    memmove(p+1, p, strlen(p)+1);
    *p = ',';
    
  }
  while (strlen(str) < 10)
  {
    memmove(str+1, str, strlen(str)+1);
    *str = ' ';
  }
  tft.print(str);
}

static inline uint32_t micros_start() __attribute__ ((always_inline));
static inline uint32_t micros_start()
{
  uint8_t oms = millis();
  while ((uint8_t)millis() == oms)
    ;
  return micros();
}

uint32_t testHaD()
{
  // pseudo-code for cheesy RLE
  // start with color1
  // while more input data remaining
  //  count =  0nnnnnnn = 1 byte or 1nnnnnnn nnnnnnnn 2 bytes (0 - 32767)
  //  repeat color count times
  //  toggle color1/color2
  static const uint8_t HaD_128x160[] PROGMEM =
  {
    0x85, 0x91, 0x09, 0x4b, 0x09, 0x24, 0x0a, 0x47, 0x09, 0x27, 0x0a, 0x44, 0x0a, 0x29, 0x0a, 0x42, 
    0x0a, 0x2b, 0x0a, 0x41, 0x0a, 0x2c, 0x0a, 0x3e, 0x0b, 0x2f, 0x09, 0x3d, 0x09, 0x32, 0x08, 0x3c, 
    0x09, 0x33, 0x09, 0x3b, 0x08, 0x33, 0x0a, 0x3a, 0x0a, 0x31, 0x0b, 0x3a, 0x0c, 0x1d, 0x01, 0x10, 
    0x0d, 0x39, 0x0c, 0x1d, 0x01, 0x10, 0x0d, 0x39, 0x0d, 0x0f, 0x01, 0x0c, 0x03, 0x0d, 0x0e, 0x39, 
    0x0e, 0x0c, 0x03, 0x0c, 0x04, 0x0b, 0x0f, 0x39, 0x0f, 0x0a, 0x04, 0x0c, 0x05, 0x09, 0x10, 0x39, 
    0x10, 0x08, 0x05, 0x0c, 0x06, 0x07, 0x11, 0x39, 0x11, 0x06, 0x06, 0x0d, 0x07, 0x04, 0x13, 0x37, 
    0x12, 0x05, 0x07, 0x0d, 0x08, 0x02, 0x15, 0x34, 0x15, 0x03, 0x08, 0x0d, 0x20, 0x32, 0x20, 0x0e, 
    0x21, 0x31, 0x20, 0x0f, 0x21, 0x2e, 0x22, 0x10, 0x22, 0x2b, 0x22, 0x12, 0x22, 0x12, 0x05, 0x12, 
    0x22, 0x14, 0x22, 0x0c, 0x0f, 0x0c, 0x22, 0x16, 0x22, 0x08, 0x15, 0x08, 0x22, 0x18, 0x22, 0x05, 
    0x19, 0x05, 0x21, 0x1c, 0x1f, 0x04, 0x1c, 0x05, 0x1f, 0x1f, 0x1c, 0x04, 0x1e, 0x04, 0x1d, 0x2b, 
    0x11, 0x04, 0x21, 0x03, 0x12, 0x36, 0x0f, 0x03, 0x24, 0x03, 0x10, 0x38, 0x0d, 0x03, 0x26, 0x03, 
    0x0d, 0x3b, 0x0b, 0x03, 0x28, 0x03, 0x0b, 0x3d, 0x0a, 0x03, 0x29, 0x03, 0x09, 0x40, 0x07, 0x03, 
    0x2b, 0x03, 0x07, 0x42, 0x05, 0x03, 0x2c, 0x04, 0x04, 0x45, 0x04, 0x03, 0x2d, 0x03, 0x04, 0x46, 
    0x02, 0x03, 0x2e, 0x03, 0x03, 0x48, 0x01, 0x03, 0x2f, 0x03, 0x01, 0x4c, 0x31, 0x4e, 0x32, 0x4e, 
    0x33, 0x4c, 0x34, 0x4c, 0x34, 0x4c, 0x35, 0x4b, 0x35, 0x4a, 0x0e, 0x03, 0x14, 0x04, 0x0d, 0x4a, 
    0x0b, 0x09, 0x0e, 0x0a, 0x0a, 0x4a, 0x0a, 0x0b, 0x0c, 0x0c, 0x09, 0x4a, 0x09, 0x0d, 0x0a, 0x0e, 
    0x09, 0x49, 0x08, 0x0f, 0x09, 0x0e, 0x09, 0x49, 0x08, 0x0f, 0x09, 0x0f, 0x08, 0x49, 0x08, 0x0f, 
    0x09, 0x0f, 0x08, 0x49, 0x07, 0x0f, 0x0a, 0x0f, 0x08, 0x49, 0x07, 0x0f, 0x0b, 0x0e, 0x08, 0x49, 
    0x07, 0x0d, 0x0e, 0x0d, 0x08, 0x49, 0x07, 0x0b, 0x13, 0x0a, 0x08, 0x49, 0x08, 0x07, 0x18, 0x08, 
    0x08, 0x49, 0x08, 0x06, 0x1b, 0x06, 0x08, 0x49, 0x09, 0x04, 0x1c, 0x05, 0x08, 0x4a, 0x09, 0x04, 
    0x1d, 0x04, 0x08, 0x4a, 0x0a, 0x03, 0x1d, 0x03, 0x09, 0x4b, 0x19, 0x02, 0x1a, 0x4b, 0x19, 0x03, 
    0x19, 0x4b, 0x18, 0x04, 0x18, 0x4d, 0x17, 0x05, 0x17, 0x4a, 0x01, 0x02, 0x17, 0x05, 0x16, 0x4a, 
    0x02, 0x02, 0x17, 0x05, 0x16, 0x02, 0x03, 0x44, 0x03, 0x03, 0x16, 0x02, 0x01, 0x02, 0x16, 0x02, 
    0x03, 0x43, 0x05, 0x03, 0x15, 0x01, 0x03, 0x01, 0x15, 0x03, 0x04, 0x41, 0x06, 0x03, 0x15, 0x01, 
    0x03, 0x01, 0x14, 0x03, 0x07, 0x3d, 0x09, 0x03, 0x2d, 0x03, 0x08, 0x3b, 0x0a, 0x04, 0x2b, 0x03, 
    0x0a, 0x39, 0x0c, 0x03, 0x2a, 0x04, 0x0b, 0x37, 0x0e, 0x03, 0x28, 0x03, 0x0e, 0x2e, 0x04, 0x03, 
    0x10, 0x03, 0x27, 0x03, 0x10, 0x03, 0x03, 0x24, 0x19, 0x03, 0x26, 0x03, 0x1a, 0x1e, 0x1d, 0x03, 
    0x24, 0x03, 0x1e, 0x19, 0x20, 0x04, 0x21, 0x03, 0x20, 0x17, 0x22, 0x04, 0x1f, 0x03, 0x22, 0x15, 
    0x22, 0x04, 0x21, 0x04, 0x21, 0x13, 0x22, 0x05, 0x15, 0x01, 0x0b, 0x05, 0x21, 0x12, 0x21, 0x06, 
    0x15, 0x01, 0x0b, 0x06, 0x21, 0x10, 0x21, 0x07, 0x0a, 0x01, 0x0a, 0x01, 0x0b, 0x07, 0x21, 0x0e, 
    0x20, 0x0a, 0x09, 0x02, 0x09, 0x02, 0x09, 0x09, 0x20, 0x0e, 0x08, 0x02, 0x15, 0x0b, 0x08, 0x03, 
    0x08, 0x03, 0x08, 0x0b, 0x15, 0x03, 0x08, 0x0d, 0x07, 0x04, 0x13, 0x0d, 0x06, 0x05, 0x06, 0x06, 
    0x05, 0x0d, 0x14, 0x04, 0x07, 0x0c, 0x07, 0x06, 0x11, 0x38, 0x12, 0x06, 0x06, 0x0c, 0x06, 0x08, 
    0x10, 0x39, 0x10, 0x08, 0x05, 0x0c, 0x04, 0x0b, 0x0f, 0x39, 0x0f, 0x0a, 0x04, 0x0c, 0x03, 0x0d, 
    0x0e, 0x39, 0x0e, 0x0c, 0x03, 0x0c, 0x02, 0x0e, 0x0e, 0x39, 0x0d, 0x0f, 0x01, 0x0c, 0x01, 0x10, 
    0x0d, 0x39, 0x0d, 0x0f, 0x01, 0x1e, 0x0c, 0x39, 0x0c, 0x30, 0x0a, 0x3a, 0x0a, 0x33, 0x09, 0x3b, 
    0x08, 0x34, 0x09, 0x3b, 0x09, 0x32, 0x09, 0x3c, 0x0a, 0x2f, 0x0a, 0x3e, 0x0a, 0x2d, 0x0b, 0x3f, 
    0x0a, 0x2b, 0x0b, 0x41, 0x0a, 0x29, 0x0b, 0x43, 0x0a, 0x27, 0x0a, 0x46, 0x0a, 0x25, 0x0a, 0x49, 
    0x09, 0x23, 0x08, 0x4e, 0x08, 0x96, 0x12 
  };

  tft.fillScreen(TFT_BLACK);

  uint32_t start = micros_start();

  tft.startWrite();

  for (int i = 0; i < 0x10; i++)
  {
    tft.setAddrWindow(0, 0, tft.width(), tft.height());

    uint16_t cnt = 0;
    uint16_t color = tft.color565((i << 4) | i, (i << 4) | i, (i << 4) | i);
    uint16_t curcolor = 0;

    const uint8_t *cmp = &HaD_128x160[0];
    tft.startWrite();
    while (cmp < &HaD_128x160[sizeof(HaD_128x160)])
    {
      cnt = pgm_read_byte(cmp++);
      if (cnt & 0x80)
        cnt = ((cnt & 0x7f) << 8) | pgm_read_byte(cmp++);

      tft.pushColor(curcolor, cnt); // PDQ_GFX has count

      curcolor ^= color;
    }
    tft.endWrite();
  }

  tft.endWrite();

  uint32_t t = micros() - start;

  tft.setTextColor(TFT_YELLOW);
  tft.setCursor(0, 145);
  tft.print(F(" http://hackaday.io/"));
  tft.print(F("         Xark"));

  delay(3 * 1000L);
  
  return t;
}

uint32_t testFillScreen()
{
  uint32_t start = micros_start();

  for (uint8_t i = 0; i < 12; i++)
  {
    tft.fillScreen(TFT_WHITE);
    tft.fillScreen(TFT_RED);
    tft.fillScreen(TFT_GREEN);
    tft.fillScreen(TFT_BLUE);
    tft.fillScreen(TFT_BLACK);
  }

  return micros() - start;
}

uint32_t testText() {
  tft.fillScreen(TFT_BLACK);
  uint32_t start = micros_start();
  tft.setCursor(0, 0);
  tft.setTextColor(TFT_WHITE); tft.setTextSize(1);
  tft.println(F("Hello World!"));
  tft.setTextColor(tft.color565(0xff, 0x00, 0x00));
  tft.print(F("RED "));
  tft.setTextColor(tft.color565(0x00, 0xff, 0x00));
  tft.print(F("GREEN "));
  tft.setTextColor(tft.color565(0x00, 0x00, 0xff));
  tft.println(F("BLUE"));
  tft.setTextColor(TFT_YELLOW);
  tft.println(1234.56);
  tft.setTextColor(TFT_RED);
  tft.println(0xDEADBEEF, HEX);
  tft.setTextColor(TFT_GREEN);
  tft.setTextSize(2);
  tft.println(F("Groop"));
  tft.println(F("I implore thee,"));
  tft.setTextSize(1);
  tft.println(F("my foonting turlingdromes."));
  tft.println(F("And hooptiously drangle me"));
  tft.println(F("with crinkly bindlewurdles,"));
  tft.println(F("Or I will rend thee"));
  tft.println(F("in the gobberwarts"));
  tft.println(F("with my blurglecruncheon,"));
  tft.println(F("see if I don't!"));
  tft.println(F(""));
  tft.setTextColor(TFT_MAGENTA);
  tft.println(F("Woot!"));
  uint32_t t = micros() - start;
  delay(1000);
  return t;
}

uint32_t testPixels()
{
  int32_t w = tft.width();
  int32_t h = tft.height();

  uint32_t start = micros_start();
  tft.startWrite();
  for (uint16_t y = 0; y < h; y++)
  {
    for (uint16_t x = 0; x < w; x++)
    {
      tft.drawPixel(x, y, tft.color565(x<<3, y<<3, x*y));
    }
  }
  tft.endWrite();
  return micros() - start;
}


uint32_t testLines(uint16_t color)
{
  uint32_t start, t;
  int32_t x1, y1, x2, y2;
  int32_t w = tft.width();
  int32_t h = tft.height();

  tft.fillScreen(TFT_BLACK);

  x1 = y1 = 0;
  y2 = h - 1;

  start = micros_start();

  for (x2 = 0; x2 < w; x2 += 6)
  {
    tft.drawLine(x1, y1, x2, y2, color);
  }

  x2 = w - 1;

  for (y2 = 0; y2 < h; y2 += 6)
  {
    tft.drawLine(x1, y1, x2, y2, color);
  }

  t = micros() - start; // fillScreen doesn't count against timing

  tft.fillScreen(TFT_BLACK);

  x1 = w - 1;
  y1 = 0;
  y2 = h - 1;

  start = micros_start();

  for (x2 = 0; x2 < w; x2 += 6)
  {
    tft.drawLine(x1, y1, x2, y2, color);
  }

  x2 = 0;
  for (y2 = 0; y2 < h; y2 += 6)
  {
    tft.drawLine(x1, y1, x2, y2, color);
  }

  t += micros() - start;

  tft.fillScreen(TFT_BLACK);

  x1 = 0;
  y1 = h - 1;
  y2 = 0;

  start = micros_start();

  for (x2 = 0; x2 < w; x2 += 6)
  {
    tft.drawLine(x1, y1, x2, y2, color);
  }
  x2 = w - 1;
  for (y2 = 0; y2 < h; y2 += 6)
  {
    tft.drawLine(x1, y1, x2, y2, color);
  }
  t += micros() - start;

  tft.fillScreen(TFT_BLACK);

  x1 = w - 1;
  y1 = h - 1;
  y2 = 0;

  start = micros_start();

  for (x2 = 0; x2 < w; x2 += 6)
  {
    tft.drawLine(x1, y1, x2, y2, color);
  }

  x2 = 0;
  for (y2 = 0; y2 < h; y2 += 6)
  {
    tft.drawLine(x1, y1, x2, y2, color);
  }

  t += micros() - start;

  return t;
}

uint32_t testFastLines(uint16_t color1, uint16_t color2)
{
  uint32_t start;
  int32_t x, y;
  int32_t w = tft.width();
  int32_t h = tft.height();

  tft.fillScreen(TFT_BLACK);

  start = micros_start();

  for (y = 0; y < h; y += 5)
    tft.drawFastHLine(0, y, w, color1);
  for (x = 0; x < w; x += 5)
    tft.drawFastVLine(x, 0, h, color2);

  return micros() - start;
}

uint32_t testRects(uint16_t color)
{
  uint32_t start;
  int32_t n, i, i2;
  int32_t cx = tft.width() / 2;
  int32_t cy = tft.height() / 2;

  tft.fillScreen(TFT_BLACK);
  n = min(tft.width(), tft.height());
  start = micros_start();
  for (i = 2; i < n; i += 6)
  {
    i2 = i / 2;
    tft.drawRect(cx-i2, cy-i2, i, i, color);
  }

  return micros() - start;
}

uint32_t testFilledRects(uint16_t color1, uint16_t color2)
{
  uint32_t start, t = 0;
  int32_t n, i, i2;
  int32_t cx = tft.width() / 2 - 1;
  int32_t cy = tft.height() / 2 - 1;

  tft.fillScreen(TFT_BLACK);
  n = min(tft.width(), tft.height());
  for (i = n; i > 0; i -= 6)
  {
    i2 = i / 2;

    start = micros_start();

    tft.fillRect(cx-i2, cy-i2, i, i, color1);

    t += micros() - start;

    // Outlines are not included in timing results
    tft.drawRect(cx-i2, cy-i2, i, i, color2);
  }

  return t;
}

uint32_t testFilledCircles(uint8_t radius, uint16_t color)
{
  uint32_t start;
  int32_t x, y, w = tft.width(), h = tft.height(), r2 = radius * 2;

  tft.fillScreen(TFT_BLACK);

  start = micros_start();

  for (x = radius; x < w; x += r2)
  {
    for (y = radius; y < h; y += r2)
    {
      tft.fillCircle(x, y, radius, color);
    }
  }

  return micros() - start;
}

uint32_t testCircles(uint8_t radius, uint16_t color)
{
  uint32_t start;
  int32_t x, y, r2 = radius * 2;
  int32_t w = tft.width() + radius;
  int32_t h = tft.height() + radius;

  // Screen is not cleared for this one -- this is
  // intentional and does not affect the reported time.
  start = micros_start();

  for (x = 0; x < w; x += r2)
  {
    for (y = 0; y < h; y += r2)
    {
      tft.drawCircle(x, y, radius, color);
    }
  }

  return micros() - start;
}

uint32_t testTriangles()
{
  uint32_t start;
  int32_t n, i;
  int32_t cx = tft.width()/ 2 - 1;
  int32_t cy = tft.height() / 2 - 1;

  tft.fillScreen(TFT_BLACK);
  n = min(cx, cy);

  start = micros_start();

  for (i = 0; i < n; i += 5)
  {
    tft.drawTriangle(
      cx    , cy - i, // peak
      cx - i, cy + i, // bottom left
      cx + i, cy + i, // bottom right
      tft.color565(0, 0, i));
  }

  return micros() - start;
}

uint32_t testFilledTriangles()
{
  uint32_t start, t = 0;
  int32_t i;
  int32_t cx = tft.width() / 2 - 1;
  int32_t cy = tft.height() / 2 - 1;

  tft.fillScreen(TFT_BLACK);

  start = micros_start();

  for (i = min(cx,cy); i > 10; i -= 5) {
    start = micros_start();
    tft.fillTriangle(cx, cy - i, cx - i, cy + i, cx + i, cy + i,
      tft.color565(0, i, i));
    t += micros() - start;
    tft.drawTriangle(cx, cy - i, cx - i, cy + i, cx + i, cy + i,
      tft.color565(i, i, 0));
  }

  return t;
}

uint32_t testRoundRects()
 {
  uint32_t start;
  int32_t w, i, i2;
  int32_t cx = tft.width() / 2 - 1;
  int32_t cy = tft.height() / 2 - 1;

  tft.fillScreen(TFT_BLACK);
  
  w = min(tft.width(), tft.height());
  
  start = micros_start();

  for (i = 0; i < w; i += 6)
  {
    i2 = i / 2;
    tft.drawRoundRect(cx-i2, cy-i2, i, i, i/8, tft.color565(i, 0, 0));
  }

  return micros() - start;
}

uint32_t testFilledRoundRects()
{
  uint32_t start;
  int32_t i, i2;
  int32_t cx = tft.width() / 2 - 1;
  int32_t cy = tft.height() / 2 - 1;

  tft.fillScreen(TFT_BLACK);

  start = micros_start();

  for (i = min(tft.width(), tft.height()); i > 20; i -= 6)
  {
    i2 = i / 2;
    tft.fillRoundRect(cx-i2, cy-i2, i, i, i/8, tft.color565(0, i, 0));
  }

  return micros() - start;
}

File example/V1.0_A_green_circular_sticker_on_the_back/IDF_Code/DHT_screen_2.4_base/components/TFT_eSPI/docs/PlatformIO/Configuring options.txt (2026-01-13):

;PlatformIO User notes:

;It is possible to load settings from the calling program rather than modifying
;the library for each project by modifying the "platformio.ini" file.

;The User_Setup_Select.h file will not load the user setting header files if
;USER_SETUP_LOADED is defined.

;Instead of using #define, use the -D prefix, for example:

; PlatformIO Project Configuration File
;
;   Build options: build flags, source filter
;   Upload options: custom upload port, speed and extra flags
;   Library options: dependencies, extra library storages
;   Advanced options: extra scripting
;
; Please visit documentation for the other options and examples
; https://docs.platformio.org/page/projectconf.html

[env:esp32dev]
platform = https://github.com/platformio/platform-espressif32.git#feature/arduino-upstream
board = esp32dev
framework = arduino
lib_deps = bodmer/TFT_eSPI@^2.4.31

build_flags =
  -Os
  -DCORE_DEBUG_LEVEL=ARDUHAL_LOG_LEVEL_DEBUG
  -DUSER_SETUP_LOADED=1
  
  ; Define the TFT driver, pins etc here:
  -DST7789_DRIVER=1
  -DTFT_WIDTH=128
  -DTFT_HEIGHT=160
  -DTFT_MISO=19
  -DTFT_MOSI=23
  -DTFT_SCLK=18
  -DTFT_CS=5
  -DTFT_DC=19
  -DTFT_RST=4
  ;-DTFT_BL=21
  ;-DTOUCH_CS=22
  -DLOAD_GLCD=1
  -DLOAD_FONT2=1
  -DLOAD_FONT4=1
  -DLOAD_FONT6=1
  -DLOAD_FONT7=1
  -DLOAD_FONT8=1
  -DLOAD_GFXFF=1
  -DSMOOTH_FONT=1
  -DSPI_FREQUENCY=27000000
